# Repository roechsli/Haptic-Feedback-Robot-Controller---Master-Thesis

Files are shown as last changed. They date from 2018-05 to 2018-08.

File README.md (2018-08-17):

# Haptic Feedback Robot Controller - Master-Thesis
This is the Master Thesis written by Roman Oechslin at University of Tokyo in 2018.

Haptic Feedback Controller - Palm Pressurization by Series Elastic Actuators in a Handheld Device

In 2016 and 2017 a research group at the University of Tokyo has designed a robot controller capable of giving palm pressurization feedback using voice coil motors (VCMs).
This project is the continuation of the research and aimed at replacing the VCMs by a Series Elastic Actuator (SEA) implementation.
A new controller has been designed and tested, varying setup parameters such as the equivalent spring constant, the actuator and gear ratio or filter design.
An underlying mathematical model has been created and verified with the frequency response data from the controller.
For testing on a real robot, designed by Topy, a communication software and graphical user interface had to be written.

Based on performance analysis, design suggestions have been made and a second controller could be developed.

The transparency and latency (response delay) have been reported for both controllers with different setup parameters settings.

yoke_handheld

game_handheld

Yoke controller - gif

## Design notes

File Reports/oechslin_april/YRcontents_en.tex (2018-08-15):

% Your name
\renewcommand{\YRname}{R. Oechslin}

% Your grade/post
\newcommand{\YRgrade}{M2}

% Submission date
\newcommand{\YRdate}{2018.Apr.27}

% Your research theme
\newcommand{\YRtheme}{Haptic Feedback Controller with Palm Pressurization}

% Work plan
\newcommand{\YRplan}{
	\hspace{-4truemm}
	\begin{tabularx}{170truemm}{|p{50truemm}||X|X|X|X|X|X|X|X|X|X|X|X|}
		\hline
		\multicolumn{13}{|c|}{\parbox[c][10truemm][c]{0truemm}{} \large Research theme: \bf \YRtheme} \\
		\hline
		\hline
		\multicolumn{13}{|c|}{\parbox[c][8truemm][c]{0truemm}{} \large \bf --- Research Plan ---} \\
		\hline
		Term \textbackslash Month & 2 & 3 & 4 & 5 & 6 & 7 & 8 & 9 & 10 & 11 & 12 & 1 \\
		\hline
		% For ``Work plan'', do not change above.
		\hline
		Literature review & & & & & & & & & & & & \\
		\shadecells{2-2}
		\hline
		Design PlayStation Controller  & & & & & & & & & & & & \\
		\shadecells{2-3}
		\hline
		Test PlayStation Controller & & & & & & & & & & & & \\
		\shadecells{4-5}
		\hline
		Design Pilot Controller & & & & & & & & & & & & \\
		\shadecells{2-4}
		\hline
		Test Pilot Controller & & & & & & & & & & & & \\
		\shadecells{4-6}
		\hline
		& & & & & & & & & & & & \\
		%\shadecells{2-10}
		\hline
		Program mbed device& & & & & & & & & & & & \\
		\shadecells{5-5}
		\hline
		Redo experiments & & & & & & & & & & & & \\
		\shadecells{5-6}
		\hline
		Make third controller? & & & & & & & & & & & & \\
		\shadecells{5-7}
		\hline
		Analyze data and compare& & & & & & & & & & & & \\
		\shadecells{7-8}
		\hline
		Write Thesis & & & & & & & & & & & & \\
		\shadecells{8-8}
		\hline
	\end{tabularx}
}

% Main contents of your work
\newcommand{\YRachievement}{
	\section{Introduction}
	A lot of research on haptic feedback in handheld devices has been conducted, not only with force feedback (\cite{Prattichizzo2012}, \cite{Schoonmaker2006}), but also with pressure stimulation (\cite{Asada2016}, \cite{Nakamura2016}). The major applications for such haptic feedback devices can be found in (minimally invasive) surgical teleoperated medical systems (\cite{Bedem2009}, \cite{Enayati2016}, \cite{Tavakoli2004}, \cite{Nisky2011}), mobile augmented reality (\cite{Bermejo2017}, \cite{Hasegawa2006}) and teleoperated robotic systems (for example in space) \cite{Christiansson2007}. However this research project focuses on implementing a feedback on a handheld controller for a non-specified group of grounded wheeled robots. The controller uses pressurization feedback as a substitution for force feedback to give an intuitive%TODO say what intuitive means, give maybe a dictionary definition
	 feeling about the intrinsic state of the robot. The tests of the controller shall be made on the commercially available crawler robot from topy \footnote{\url{http://www.topy.co.jp}} using two tracks as means of transportation.
	
	As an initial approach and to be consistent with the previous research in this area \cite{AsadaPre} the robots orientation (pitch and roll angles) have been taken as state of interest. As an alternative measure, the current in the two crawler motors can be fed back to the user, to have a rough idea of used energy and to make it detectable if the robot is being stuck or blocked somewhere.
	
	\subsection{Project Description and Status Quo in the Beginning of the Project}
	The handheld controller that has been designed at Yamamoto's lab in 2016 and 2017 uses voice coil motors (VCMs) for the feedback%TODO cite paper
	. The disadvantage of these motors is that a constant voltage has to be applied to maintain a constant force. This leads to an energy-inefficient system and produces a lot of extra heat. Furthermore, the motors were rated at $13.6$ V with $2$ N/A. In the current implementation, the output force of each palm stimulator was exactly $2$ N.\\
	 The testing environment for this controller consisted in a Unity program that let the user control a tank with crawlers in an artificial landscape. When driving over the hills and smaller bumps, the user feels the magnitude of the tilt (orientation angles roll and pitch) as a pressure on the palms. \\
	The goal of this work is to replace the VCM by a set of series elastic actuators (SEAs). Different SEA-based controller designs shall be prototyped and tested on a real robot (topy). Furthermore, various feedback laws shall be implemented and tested to find the most intuitive feedback for the state of the robot.
	
	\section{Design and Analysis}
	\subsection{Series Elastic Actuators}
	%TODO The advantage of the SEA is that the elastic spring element in the system reduces the forces control to a distance control (the compression of the springs). Additionally, the elastic element is shock absorbent and stable for different environments. This means that the controller can be stable even when used with different grip stiffness, for example. \\
	 %TODO Alternatively, if the motors are non-backdriveable, a constant force can be created with only momentary motor voltage application.
	The principle of series elastic actuators is relatively simple. The concept is explained in \cite{Pratt1995} which also mentions a more accurate and stable force control and the possibility of energy storage. A thorough study of an SEA design and its analysis has been made in \cite{Junior2016}, stating that the most important parameter in the system is the spring constant. Therefore, springs with several different spring constants have been used for the analysis of this research project.\\
	In this study, two different SEA designs have been implemented and tested. The first design is based on a linear movement (constrained by a linear guideway), where the rotary motion of the motor is driving a lever, pushing the carriage back and forth. For more details, see figure \ref{fig:actuation_system_explained}. \\
	The second design is an approximated linear motion, due to a very large lever (rotational-L) actuated by a cam principle.
		
	\subsection{Design of the PlayStation Controller}
	The first design of the haptic feedback controller has been partially inspired by the existing design and partially by the commercial controllers of PlayStation. The controller can be seen in figure \ref{fig:centric_shaft_controller_smaller}.
	
	\begin{figure}[h!]
		\centering
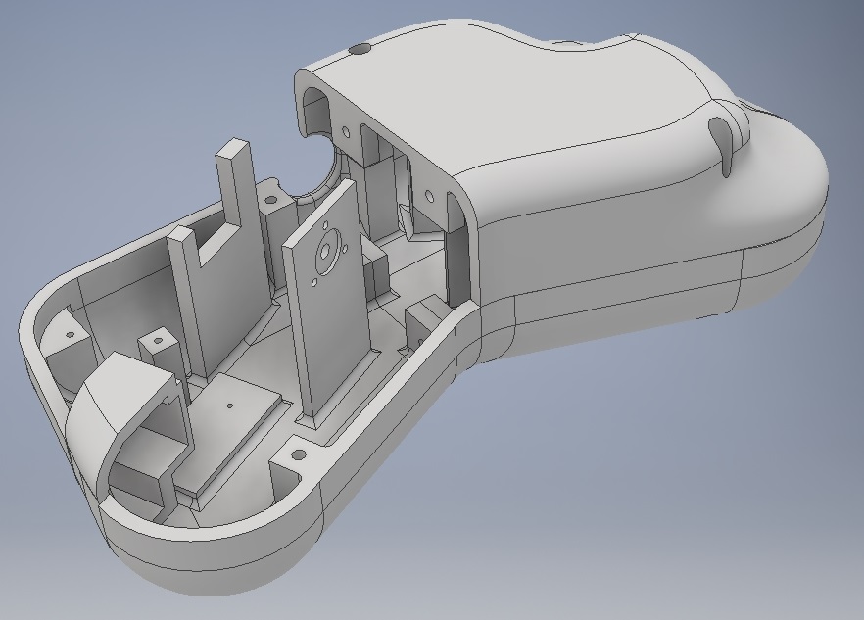
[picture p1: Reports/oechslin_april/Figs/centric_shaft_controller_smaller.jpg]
		
		\caption{3D model of the PlayStation controller.}
		\label{fig:centric_shaft_controller_smaller}
	\end{figure}
	
	This design of the controller aims at having a natural position for the hands, such that the user can hold the controller for a long time without having the hands in an awkward position. As it can be seen in the figure, the palm pads that transmit the feedback pressure to the palms are not directed perpendicularly towards the user, but rather outwards at a certain angle (refer to figure \ref{fig:centric_shaft_controller_smaller_top_view}). This can be seen as a drawback, since the user is expected to have the most intuitive feeling with a feedback opposing the driving direction (ie. perpendicular).
	\begin{figure}[h!]
		\centering
		
		\caption{3D model of the controller and the feedback direction indication.}
		\label{fig:centric_shaft_controller_smaller_top_view}
	\end{figure}

	The dimensions of the controller are 220mm in length, 110mm in width and 70mm in height. The controller is unusually thick due to the feedback actuation design. This actuation design can be seen in figure \ref{fig:actuation_system_explained}. The motor shaft is rotating a clamp link which is attached to a 3D-printed part, called connecting link. This 3D-printed part is attached to the carriage, an also 3D-printed part called L-plate, and is screwed to the linear guideway. The L-plate is connected via a set of springs (of variable spring constants) to the palm pad, thus making it an SEA. The linear guideway keeps the palm pad in a linear motion.
	\begin{figure}[h!]
		\centering
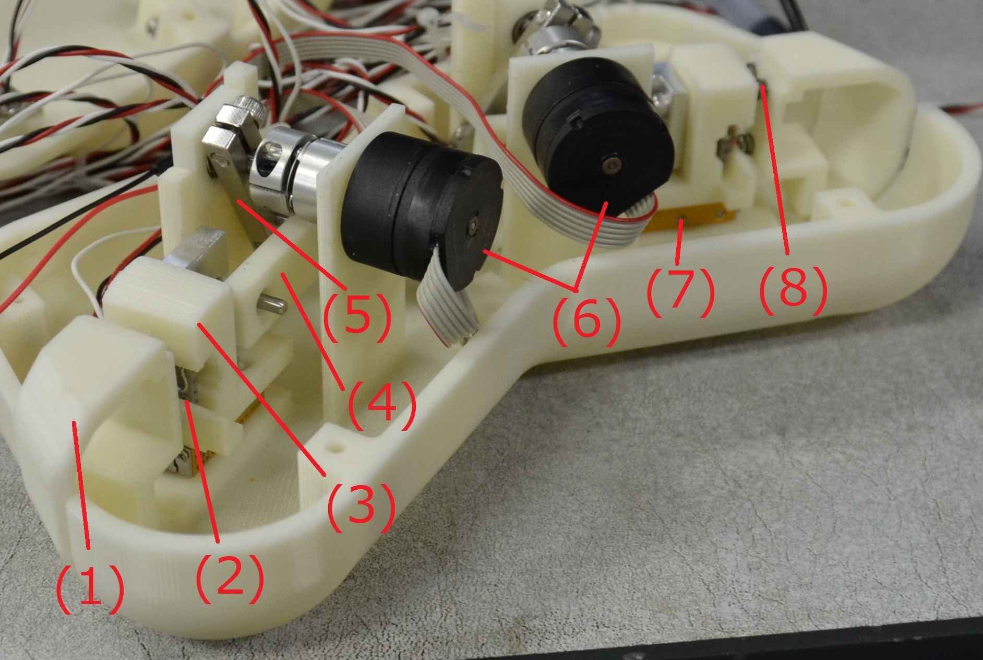
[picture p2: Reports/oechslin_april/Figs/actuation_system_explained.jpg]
		
		\caption{Actuation system with legend.}
		\label{fig:actuation_system_explained}
	\end{figure}

	The legend refering to the actuation system in figure \ref{fig:actuation_system_explained} is as follows:
	\begin{itemize}
		\item (1) : Palm pad
		\item (2) : Photoreceptor
		\item (3) : L-plate
		\item (4) : Connecting link
		\item (5) : Clamp link
		\item (6) : Motors
		\item (7) : Linear guideway
		\item (8) : Springs
	\end{itemize}

	\subsubsection{Design of the Pilot Controller}
	The 3D model of the left-hand side pilot-based controller can be seen in figure \ref{fig:left_hand_joystick_cam}. To see the inside of the controller, the cover has been removed. To assemble it three sets of screws and nuts are necessary, making it easy to assemble and take apart. Also, this design is smaller in volume than the PlayStation controller. It is therefore more slender, cheaper and faster to manufacture.
	\begin{figure}[h!]
		\centering
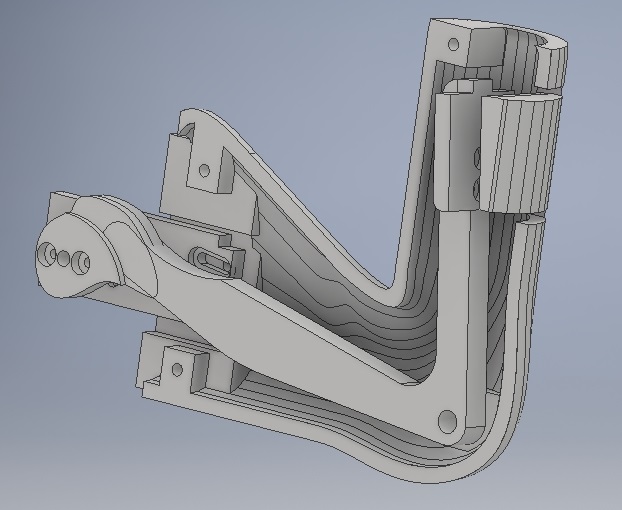
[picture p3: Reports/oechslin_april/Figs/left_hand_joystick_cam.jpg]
		
		\caption{3D model of the left-hand side controller with a removed cover.}
		\label{fig:left_hand_joystick_cam}
	\end{figure}

	In this design, the feedback motion is perpendicular towards the user and opposing the direction of motion. However, there is a slight angle at which the force is acting, due to the rotational design in the controller. But due to the large lever, this effect can be neglected. The actuation principle is based on a simple cam disk that directly pushes the rotational-L. For this design, the motors with a higher reduction gear ratio have been foreseen.

	\subsection{Test Environment and Programs}
	To test the controller, it was necessary to write a properly working environment. The topy robot is communicating via a wireless serial link. It has a prespecified communication message that consists in $70$ bytes for sending from the robot to the PC and $44$ bytes for message to receive. These messages include the bytes reserved for proper starting and ending as well as the checksum. \\
	It was thus necessary to write an application that reads out the position of the two joysticks (basic potentiometers principle) and construct a message including these joystick values as speed reference for the robot. Then the message has to be sent over the wireless serial link to the robot and the answer has to be received. The important sensor readings (inclination, current in the crawlers, passed time and battery level) have to be read out and a feedback according to the chosen feedback law has to be sent to the motors.\\
	For this purpose, the programming language processing \footnote{\url{https://processing.org/}} has been used to create a graphical user interface and to establish the serial connection. For low-level motor control purposes an Arduino Uno has been used. The parameters that can be set for testing purposes can be seen in table \ref{tab:programming_params}.
	
	\begin{figure}[h!]
		\centering
		\begin{tabular}{|l|c|l|}
			
			\hline
			Setting & Value & Units \\ \hline \hline
			Baud rate for robot serial link & $9600$ & [bps]\\ \hline
			Baud rate for Arduino serial link & $9600$ & [bps] \\ \hline
			Update rate of the processing GUI & $5$ & [Hz] \\ \hline
			Update rate of the Arduino motor controller (in theory) & $200$ & [Hz] \\ \hline
			Update rate of the Arduino motor controller (in practice) & $170$ & [Hz] \\ \hline %TODO this should be in measured not in set parameters
			Max voltage for motor & $20$ & [V] \\ \hline
			Feedback resolution & 5 out of 255 & [-] \\ \hline
			PWM frequency & $31372.55$ & [Hz]  \\ \hline
			Proportional motor gain & $1.5$  & [-] \\ \hline
			Integral motor gain & $0.0$  & [-]\\ \hline
			Derivative motor gain & $0.0$  & [-]\\ \hline
			Feedback filter  & $50$ & [\%] \\ \hline %TODO calculate cut off frequency
			Left photoreceptor MIN value & $500$ & [-] \\ \hline %TODO explain more in detail what these values mean
			Left photoreceptor MAX value & $770$ & [-] \\ \hline
			Right photoreceptor MIN value & $680$ & [-] \\ \hline
			Right photoreceptor MAX value & $770$ & [-] \\ \hline			
		\end{tabular}
		\caption{Software parameters.}
		\label{tab:programming_params}
	\end{figure}
	
	\subsection{GUI in Processing}
	The graphical user interface shows the current feedback method as well as the magnitude. It also indicates which driving direction (forward, backward or halt) is sent to the robot. Since there is no control of the battery charge in the robot, it sends battery information in its message to the PC. The processing program reads out the charge of the battery and warns the user if it is too low. It stops the program, if the battery state is critical. The feedback method can be changed by a mouse-click anywhere in the window. The GUI can be seen in figure \ref{fig:processing_gui}.
	 
	\begin{figure}[h!]
		\centering
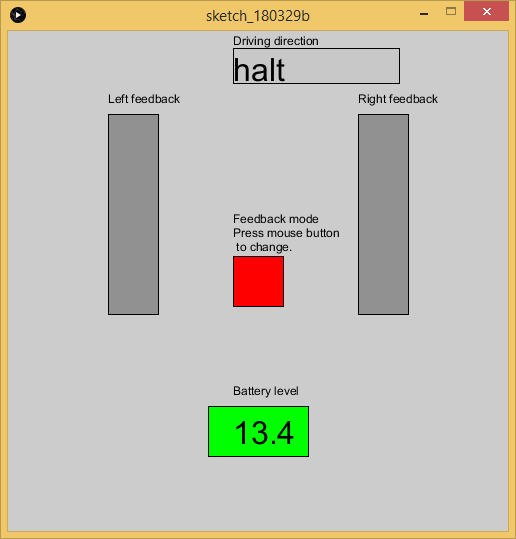
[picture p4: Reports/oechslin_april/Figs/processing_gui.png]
		
		\caption{Graphical user interface written in processing.}
		\label{fig:processing_gui}
	\end{figure}

	This application handles the messages sent to and from the robot.
	
	\subsection{Control Scheme}
	The control scheme is based on a simple proportional controller. The scheme can be seen in figure \ref{fig:control_scheme}. In the test setup the reference signal $dist_{ref}$ is given by the sinusoidal function generator. In the operational mode, this corresponds to the target output force, also called the haptic feedback force that should be felt by the user. Ideally, this shall be a function of orientation (roll and pitch) as well as the current in the two crawlers.
	\begin{figure}[h!]
		\centering
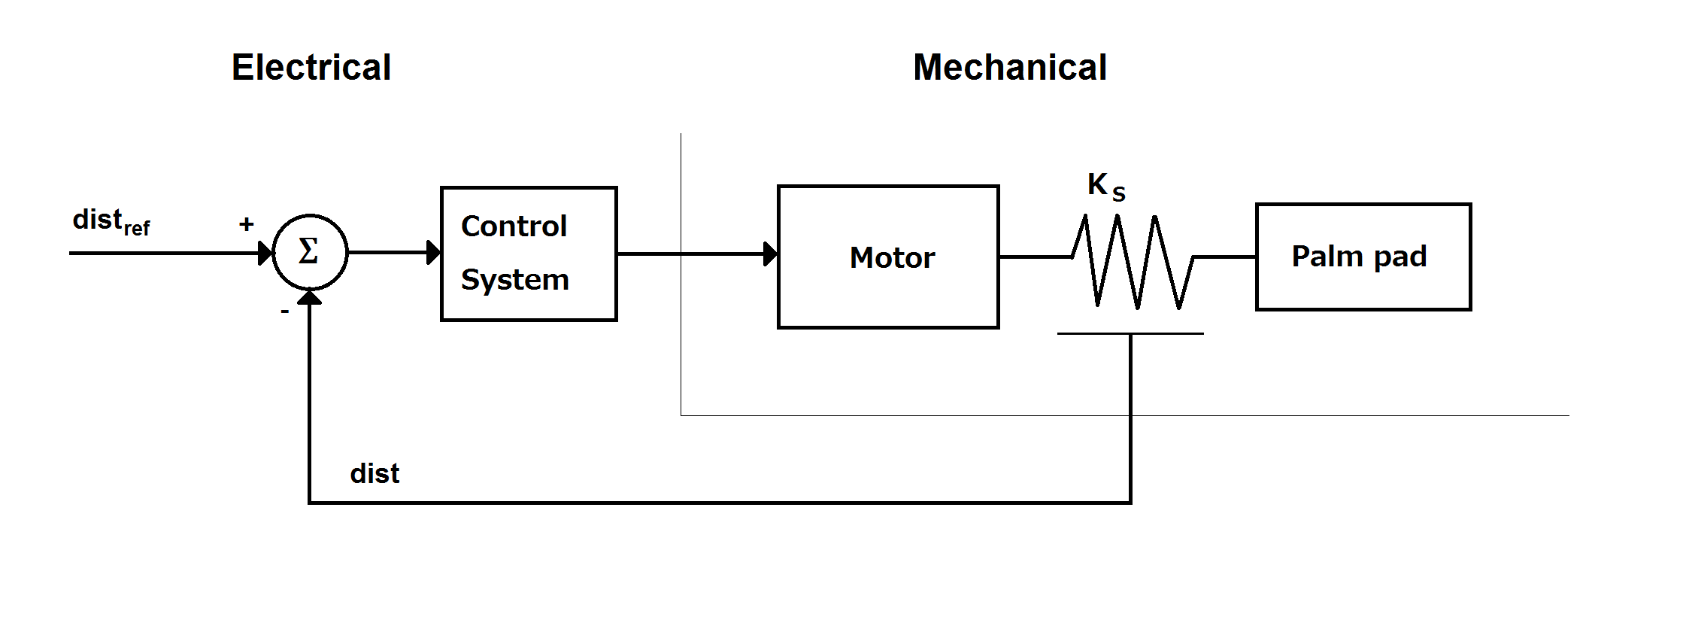
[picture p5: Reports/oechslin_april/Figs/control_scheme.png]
		
		\caption{Control scheme for the haptic feedback system.}
		\label{fig:control_scheme}
	\end{figure}
	
	\subsection{Electrical low-pass Filter}
	Before the PWM signal from the Arduino is sent to the amplifier, where it is amplified to control the motors, it has been filtered with a simple RC low-pass filter. The resistor has a value of $3.9$ k$\Omega$ and the capacitor of $0.1$ $\mu$F. This smooths out the PWM signal and has been implemented in order to avoid that the amplifier tries to follow the Arduino signal with unnecessary precision, eventually causing too much heat.

	\subsection{Photoreceptor Circuit}
	The photoreceptor that has been used is the TPR-105 from GENIXTEK CORP. Its sensing characteristics can be seen in figure \ref{fig:photoreceptor_curve}. The electrical circuit can be seen in figure \ref{fig:tpr105_circuit}. The component values are $R_1 = 330 \Omega$, $R_2 = 62$k$\Omega$ and $V_{CC} = 5$V. This receptor returns a $10$-bit value.
	
	\begin{figure}[h!]
		\centering
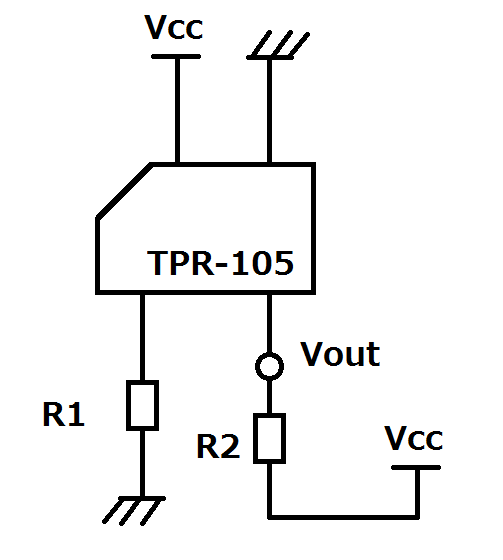
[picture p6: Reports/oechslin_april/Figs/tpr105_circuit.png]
		
		\caption{Implementation circuit of the photoreceptor.}
		\label{fig:tpr105_circuit}
	\end{figure}
	\begin{figure}[h!]
		\centering
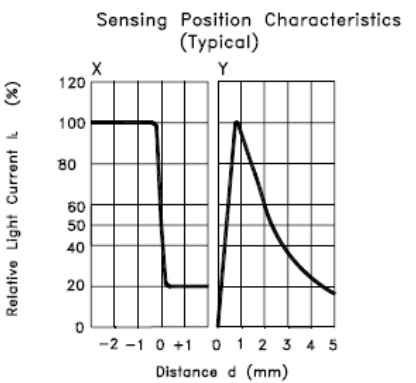
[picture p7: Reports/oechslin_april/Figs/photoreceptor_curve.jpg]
		
		\caption{Sensing characterstics of the photoreceptor TPR-105. Taken from its datasheet.}
		\label{fig:photoreceptor_curve}
	\end{figure}

	The sensing characteristics shows a nonlinear function in the range between $1$mm and $5$mm. However, as a first step, this has been interpolated linearly. To put it more precisely, the target output force has been mapped linearly to the measured distance. The operational distance lies between $4.5$mm to $5.5$mm.
	
	\section{Testing of the PlayStation Controller}
	For the two sides of the controller two different spring constants have been used. On the left-hand side, there is a set of three springs with a constant of $0.98$N/mm each. The motor has a reduction gear ratio of $33:1$. On the right-hand side the springs have a constant of $9.8 $N/mm and the motor has a reduction of $112:1$. The parameters are resumed in table \ref{tab:playstation_charac}.
	
	\begin{figure}[h!]
		\centering
		\begin{tabular}{|l|c|c|l|}
			\hline
			& Left side & Right side & Units\\ \hline \hline
			Clamp link length & 20 &  20 & [mm]  \\ \hline
			Motor reduction & $33:1$ & $112:1$ &  [-] \\ \hline
			Output torque (continous) & $30$ & $93$ & [mNm]  \\ \hline
			Output torque (intermittent) & $100$ & $180$ & [mNm] \\ \hline
			Number of springs used & $3$ & $3$ & [-] \\ \hline
			Spring constant & $0.9$ & $9.8$ & [N/mm] \\ \hline
			Equivalent spring constant & $2.7$ & $29.4$ & [N/mm] \\ \hline
		\end{tabular}
		\caption{Motor setup characteristics}
		\label{tab:playstation_charac}
	\end{figure}

	In order to conduct the frequency response analysis, the SG-4115 Function Generator has been used. The output signal was a sine wave with a peak-to-peak value of $2$V and an offset of $1.4$V. These settings have been made in order to stay within the detectable range of the Arduino $[0..5]$V. The frequency has been varied between $0.1$Hz and $35$Hz with $20$ logarithimcally spaced steps.
	
	Since the palm pads are blocked by the users hand in operational mode, they may not be considered blocked by an infinitely stiff wall. Therefore two different test setups have been created, where the palm pad has first been blocked by a screw driver in both directions, to have close to infinite stiffness, and a second setup, where the palm pads have been blocked by the users hands.
	
	\subsection{Results for Fixed Palm Pad Experiment (Pseudo Infinite Stiffness)}
	The input signal has been received as a feedback value (ie. $dist_{ref}$) and the P-controller stated in table \ref{tab:programming_params} controlled the output force by linearly mapping it to the photoreceptor distance. The measured distance has been logged and plotted. As it was expected, it is between the two extreme values stated in table \ref{tab:programming_params} (MIN and MAX). The response for the two extreme frequencies can be seen in figure \ref{fig:resp_left_hand_rigid_experim1}.
	\begin{figure}[h!]
		\centering
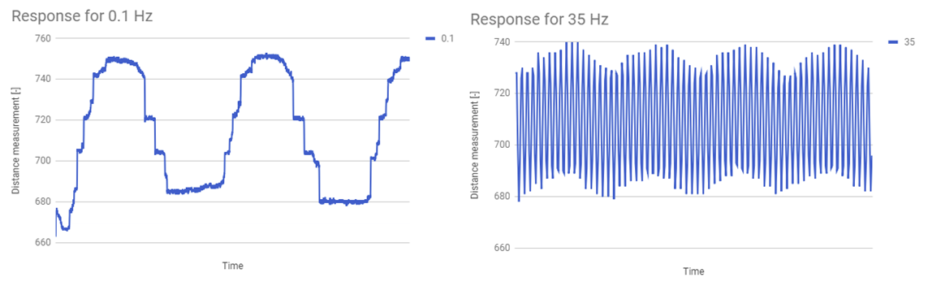
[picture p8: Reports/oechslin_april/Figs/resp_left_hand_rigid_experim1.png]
		
		\caption{}
		\label{fig:resp_left_hand_rigid_experim1}
	\end{figure}
	
	In order to find the frequency response, one is interested in the amplitude correlation between the input signal and the output signal, as given in the following equation:%TODO write how the FRF can be found, find a paper and reference it
	\begin{equation}
		H = \frac{F^*(j\omega)}{F(j\omega)}
	\end{equation}
	Where $F^*(j\omega)$ is the transfer function of the output signal and $F(j\omega)$ of the input signal.\\
	To calculate the amplitude of the output function (the measured value by the photoreceptor, corresponding to the distance between sensor and palm pad) one should ideally have a distinguishable value which is given by the maximal and minimal value of the sinusoidal output function. However, due to noise in the system, a sometimes occurring drift, interpolation aliasing and other effects such as the plateau characteristics shown in figure \ref{fig:resp_left_hand_rigid_experim1} and discussed in a later section, these minimum and maximum values are not clearly defined. Therefore, two different approaches have been chosen for the pseudo infinitely blocked palm pad experiment.
	
	First, the two quartile values ($Q_1$ and $Q_3$) have been calculated based on all the data, including outliers and noise. This is a relatively time-efficient method and is supposed to be less accurate since it sometimes includes errors such as the initial downward spike shown in the figure \ref{fig:resp_left_hand_rigid_experim1} for $0.1$Hz. The difference between these two quartile values has then been divided by the difference of the quartiles of the input signal ($Q_{3(sine)} - Q_{1(sine)}$). The results are indicated by the blue lines in figure \ref{fig:freq_resp_both_hands_rigid_experim1}.

	\begin{figure}[h!]
		\centering
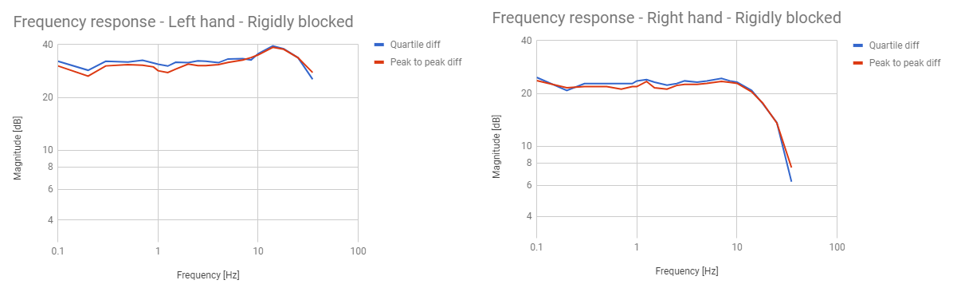
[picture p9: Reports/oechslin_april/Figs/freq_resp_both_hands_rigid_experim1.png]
		
		\caption{Frequency response analysis for both hands with a pseudo infinitely blocked palm pad.}
		\label{fig:freq_resp_both_hands_rigid_experim1}
	\end{figure}

	As an alternative output function, the amplitude has been measured manually, taking an average over several minima and maxima. This method is much more time consuming, but allows for filtering the noisy parts of the measurement, since it requires a visual representation of the measured data. These values are indicated on the same figure by the orange lines.
	
	\subsection{Results for Hand-Blocked Palm Pads Experiment}
	In the second experimental setup, the palm pads have been blocked by the hands of the user, to simulate an environment closer to the operational mode. This time, only the quartile method has been used to calculate the amplitude of the output signal. The results can be seen in figure \ref{fig:freq_resp_both_hands_soft_experim1}.
	\begin{figure}
		\centering
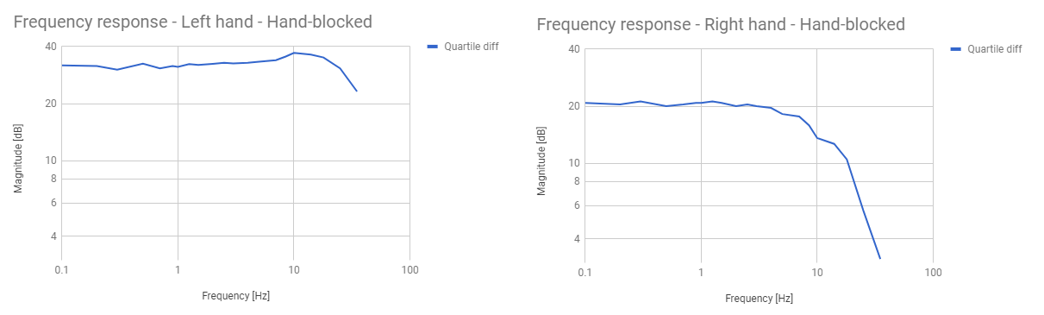
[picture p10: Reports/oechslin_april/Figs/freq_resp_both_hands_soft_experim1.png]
		
		\caption{Frequency response analysis for both hands with a hand-blocked palm pad.}
		\label{fig:freq_resp_both_hands_soft_experim1}
	\end{figure}
	
	The order of the system can be identified when looking at the slope of the Bode plot after its resonance top\footnote{Acutally, one should also consider the phase plot, but due to the reasons mentioned later in this research, this step has been skipped.}. This has been calculated for the six different curves and the following slopes have been found:
	
	\begin{tabular}{|c|c|c|}
		\hline 
		Rigid & left hand, blue line & $-54$ dB per dec \\ 
		\hline 
		& left hand, orange line & $-65$ dB per dec \\ 
		\hline 
		& right hand, blue line & $-54.8$ dB per dec \\ 
		\hline 
		& right hand, orange line & $-60.4$ dB per dec \\ 
		\hline 
		Soft & left hand & $-62.4$ dB per dec  \\ 
		\hline 
		& right hand & $-41.1$ dB per dec \\ 
		\hline 
	\end{tabular} 
	
	\section{Discussion}
	\subsection{Control Scheme and GUI}
	The control scheme is a simple proportional controller. It has been tested and decided to work well enough. If time permits, an integration and fine-tuning of an integral and derivative term can be done. \\
	There is not much to say about the GUI, however the handling of messages is not always done successfully. From time to time the processing program receives a message from the robot which is not complete. This results in accessing a cell of an array that is out of boundaries and the program crashes. To ensure the stability of the program, this case needs to be handled.
	
	\subsection{Design and Fabrication of the PlayStation Controller}
	The design of the controller is rather bulky and the actuation system might be too complex for what it is supposed to do. Due to its size, the upper and lower parts do not fit in the 3D printer and had to be cut in half and assembled by screws. This adds an extra step in manufacturing and assembly, making it more time-consuming. However the overall assembly is quite easy and tolerances have been chosen such that the whole system works. The feedback direction is not chosen optimally, if one aims at having a feedback opposing the driving direction (as seen from the robot).
	
	\subsection{Design and Fabrication of the Pilot Controller}
	This controller has almost been fully assembled, however not tested yet. It is much more simple to manufacture, as well as assemble. This design focused on having a feedback opposing the direction of motion.

	\subsection{Frequency Response Function}
	Figure \ref{fig:resp_left_hand_rigid_experim1} mainly shows two things. Firstly, there seems to be a certain step size, which is considerably more than expected. This results in only few values to attain for the photoeceptor, which can easily be seen in the response for $0.1$Hz. The second thing is, that at higher frequencies the Arduino has a too low update frequency and cannot follow the imposed sine signal, resulting in some aliasing effects. This shows that the Arduino is not capable of following frequencies higher than $35$Hz, but it also shows that the Arduino is not the right choice as a control device. The data analysis is therefore only to take with a grain of salt, since the important region after the resonance top had to be cut off. Future experiments shall be conducted using an mbed device, capable of operating at a control loop frequency of at least $1$kHz.
	
	As it can be seen in figure \ref{fig:freq_resp_both_hands_rigid_experim1} the two different methods of measuring the amplitude of the output signal share the same allures to a certain extent. This legitimizes to use the much more time-efficient approach of calculating the amplitude using the two quartile values. This argument has already been used for the data analysis in the experiment where the palm pads have been blocked by the users hand.
	
	The two figures \ref{fig:resp_left_hand_rigid_experim1} and \ref{fig:freq_resp_both_hands_rigid_experim1} show similar characteristics. Based on this, it seems appropriate to treat the two cases of pseudo infinite stiffness and hand-blocked palm pads as the same environment and for ease of analysis, only one of the two cases shall be treated.

	\section{Conclusion}
	The data that has been gathered with the Arduino as control device is only significant to a certain extent. The conclusions of using a screwdriver to block the palm pads for the experiments instead of the hand is still valid. However, the investigated frequency regions are too low to draw a meaningful conclusion and thus needs to be studied in more detail with a different control device (ie. an mbed). In addition to that, the phase diagrams have to be taken into account to confidently determine the order of the system.\\
	Furthermore, the most sensitive range of the photoreceptor is between $1$mm and $2$mm. The current implementation however is at a distance of roughly $5$mm making it much less linear and also less sensitive. This distance shall be reduced to increase linearity and sensitivity.

	\section{Outlook}
	First, the measured distance of the photoreceptor shall be changed to be in the range of $1.5$mm to $2.5$mm to have maximum linearity and sensitivity.\\
	The next step is to program the mbed to achieve the same control structure as with the Arduino, only with a higher control frequency. This should make it possible to study the system for higher frequencies. The control frequency shall be of $1$kHz, aiming for a maximum frequency of $100$Hz (Nyquist frequency is $f_s = 500$Hz and the practically achievable frequency is roughly one $5$th of this value).\\
	The experiments shall be conducted and analyzed again, this time also taking into account the phase plot in the Bode diagram. \\
	Additionally, the second controller shall be fully assembled and tested in the same manner.\\
	In parallel, the datasheet of the PMA servo motor driver shall be translated into English and the device integrated in the setup.

	%ここまで
}

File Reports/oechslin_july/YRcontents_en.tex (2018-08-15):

% Your name
\renewcommand{\YRname}{R. Oechslin}

% Your grade/post
\newcommand{\YRgrade}{M2}

% Submission date
\newcommand{\YRdate}{2018.Jul.31}

% Your research theme
\newcommand{\YRtheme}{Haptic Feedback Controller with Palm Pressurization}

% Work plan
\newcommand{\YRplan}{
	\hspace{-4truemm}
	\begin{tabularx}{170truemm}{|p{50truemm}||X|X|X|X|X|X|X|X|X|X|X|X|}
		\hline
		\multicolumn{13}{|c|}{\parbox[c][10truemm][c]{0truemm}{} \large Research theme: \bf \YRtheme} \\
		\hline
		\hline
		\multicolumn{13}{|c|}{\parbox[c][8truemm][c]{0truemm}{} \large \bf --- Research Plan ---} \\
		\hline
		Term \textbackslash Month & 2 & 3 & 4 & 5 & 6 & 7 & 8 & 9 & 10 & 11 & 12 & 1 \\
		\hline
		% For ``Work plan'', do not change above.
		\hline
		Literature review & & & & & & & & & & & & \\
		\shadecells{2-2}
		\hline
		Design PlayStation Controller  & & & & & & & & & & & & \\
		\shadecells{2-3}
		\hline
		Test PlayStation Controller & & & & & & & & & & & & \\
		\shadecells{4-6}
		\hline
		Frequency Response Analysis & & & & & & & & & & & & \\
		\shadecells{5-6}
		\hline
		Design Pilot Controller & & & & & & & & & & & & \\
		\shadecells{4-6}
		\hline
		Test Pilot Controller & & & & & & & & & & & & \\
		\shadecells{6-7}
		\hline
		& & & & & & & & & & & & \\
		%\shadecells{2-10}
		\hline
		Theoretical Analysis & & & & & & & & & & & & \\
		\shadecells{6-7}
		\hline
		Analyze data and compare & & & & & & & & & & & & \\
		\shadecells{7-8}
		\hline
		Write Thesis & & & & & & & & & & & & \\
		\shadecells{8-8}
		\hline
	\end{tabularx}
}

% Main contents of your work
\newcommand{\YRachievement}{
	
\section{Introduction}
This report is the continuation of the first two reports about the project "Haptic Feedback Controller with Palm Pressurization". The last report has stated the tracking behavior of a simple P- and PID-controlled device for a sine reference of various frequencies. Furthermore, it has suggested an experimentally identified equivalent spring damping coefficient which can be used to model the setup analytically.\\
This report is first introducing a thorough literature research into the haptic teleoperated field of study. Then it will discuss the results of the tested controller and give advice on how to choose system and setup parameters for future and related work. 

\section{Project Introduction}
\subsection{Haptics}
The Oxford Dictionaries define haptics as 

%\begin{displayquote}
"Relating to the sense of touch, in particular relating to the perception and manipulation of objects using the senses of touch and proprioception." \cite{Oxford}
%\end{displayquote}
It dates the term back to the late 19th century	and states its origin from the greek words \textit{haptikos} meaning 'able to touch or grasp' and \textit{haptein}, 'fasten'.\\
In engineering, the research in the haptic field has started to emerge in late nineteen-eighties \cite{Srinivasan1995}. Before that, man-machine interaction was mainly limited to keyboard and mouse input, which is rather unidirectional and passive and it soon has become clear that this requires a more skilled user for all kinds of operations. This directly leads to limitations in performance. Haptics can extend this unilateral interaction by providing tactile or kinesthetic information. This combination can overcome the users limitations and improve performances of high-precision tasks or high-force tasks drastically.\\
\cite{Hayward2004} states, that even though the research in the haptic domain in the past ten years has significantly increased, further investigations are necessary for the "quest for realism", especially in medical telesurgical applications where realism is key to performance. Other application domains include space operations, manufacturing, physical rehabilitation, arts or simply entertainment related devices.\\
\cite{Adams1998} states the critical elements for stability of haptic setups, mainly focusing on haptic simulations. It also motivates exploration of alternative control techniques due to the unpredictability of the human operator and the environment model.
%why haptics and what is it, needs identification

%TODO stated already in april \subsection{Previous Research at Yamamoto's Lab}
%what are the problems of the research before i came
%TODO stated already in april \subsection{Literature Review}
%what are some similar applications
%TODO stated already in april \subsection{Project Scope}
%what are my goals

\section{Stability and Transparency Trade-Off}
Even though the controller cannot be seen as a master-slave teleoperation setup, the problem settings of stability and transparency still apply. They are the main problems related to haptics and haptic teleoperation applications \cite{Christiansson2007}. Often, the stability issues arise from master-slave mass mismatch and stiffness of the environment. But high inertia also poses problems for higher frequencies. In this research however, the masses and frequencies are relatively low. \\
The stability of this controller is not only affected by the control scheme and the mechanical setup, but also by the operator, whose grasp can render a system stable or unstable \cite{Enayati2016}. Additionally, communication delays can also cause instability.\\
To gain insight into the stability, literature uses for example the root-locus method \cite{Christiansson2006} or the notion of passivity. For haptics, it can generally be assumed that the operator is passive \cite{Hogan1989}. Alternatively, one can also use the real data of the implementation to subjectively assess the stability. Here, the latter approach has been chosen.

%Hannaford shows that a cable driven hand-controller has similar frequency characteristics, where the resonance frequency is slightly more elevated than the SEA device.

\section{PlayStation-Controller Testing}
\begin{figure}[h!]
	\centering
	
	\caption{Topy robot for real-world controller test setup.}
	\label{fig:topy_robot}
\end{figure}
After the theoretical analysis and model identification of the PlayStation-controller, the setup has been put to the test. At first, the controller has been connected to the computer to communicate with the Topy robot. The communication software was written in processing \cite{Fry2018} and is explained in a different section.\\ %TODO write about the software somewhere, reference here
\subsection{Latency}
The controller was successfully able to navigate the robot, if with a delay of roughly $700$ms. The commercial controller, that was developed for the Topy robot, also had a certain delay of almost $500$ms. This delay is the difference between the instant when the joystick is pushed forward, and the moment when the robot starts moving. The feedback methods that have been tested varied between a pure pitch feedback, a combined pitch and roll feedback and a current consumption feedback law. \\%TODO state the feedback laws and reference here
The effect and magnitude of the command latency, but also of the feedback latency can be seen in figure \ref{fig:real_P_scope_13_latency_plot} and \ref{fig:real_PID_scope_14_latency_plot}.

\begin{figure}[h!]
	\centering
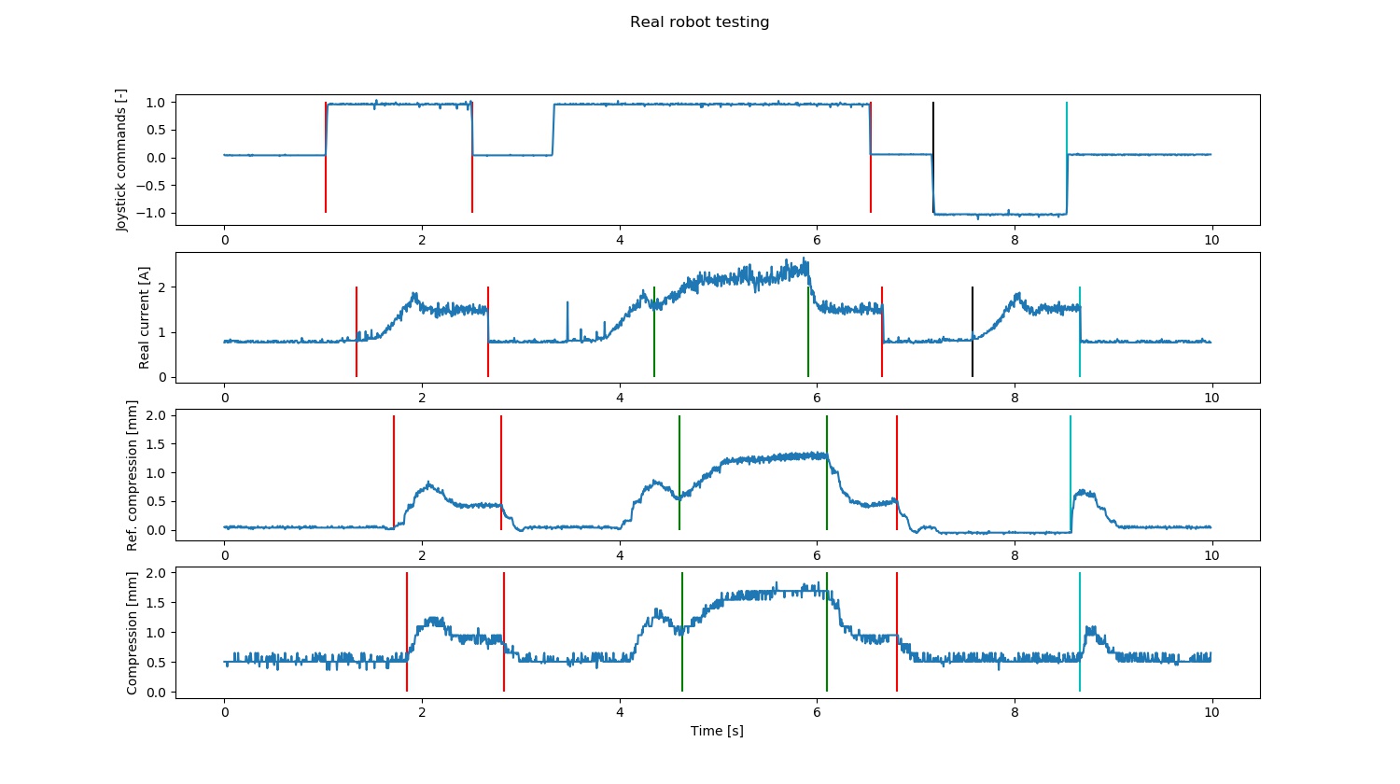
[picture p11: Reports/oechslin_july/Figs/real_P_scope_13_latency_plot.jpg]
	
	\caption{Command and behavior of Topy robot with P-controlled PlayStation controller.}
	\label{fig:real_P_scope_13_latency_plot}
\end{figure}

\begin{figure}[h!]
	\centering
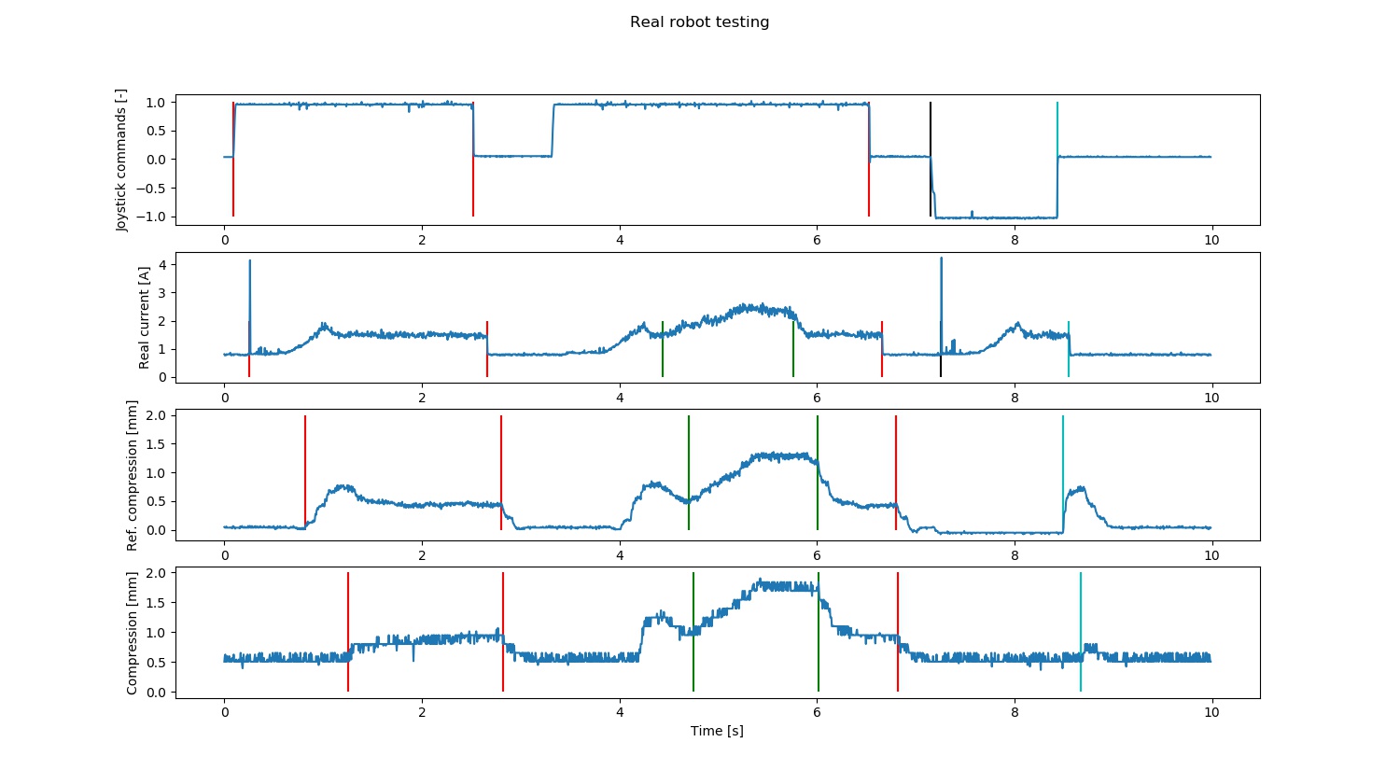
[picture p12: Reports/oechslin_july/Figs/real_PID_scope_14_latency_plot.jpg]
	
	\caption{Command and behavior of Topy robot with PID-controlled PlayStation controller.}
	\label{fig:real_PID_scope_14_latency_plot}
\end{figure}

In these figures, several interesting things have to be mentioned. First of all, the delay between sending the commands and receiving the consumed current value, which is then used as feedback value, is roughly $700$ ms. The delay between the received feedback value and the response of the distance sensor is much smaller and depends on the situation of the robot. When the robot starts to move, it takes some time until the current has built up, and the latency between the reference compression and actual compression is roughly $130$ ms for the P-controlled, and $430$ ms for the PID-controlled setup (see first red vertical lines). However, when the robot is stopped, the latency is $20$ - $30$ ms (second and third red lines).\\
In the first green lines, an external force has been applied to the robot, simulating an obstacle, which increased the consumed current and therefore also increased the desired feedback value. Again, the latency was of roughly $30$ ms. The second green lines is where the external force has been removed and the current dropped abruptly back to its normal value. The latency here was below $10$ ms.\\
Also indicated in figures \ref{fig:real_P_scope_13_latency_plot} and \ref{fig:real_PID_scope_14_latency_plot}, one can see that the feedback has been turned off when driving backwards (balck lines). However, in this scenario the feedback has been activated when standing still, ie. sending $0$ as driving speed. Since the robot is only sending the magnitude but not the direction of the current in the crawlers, the remaining current from the backward motion is fed back. This mode can easily be turned off, such that no feedback is felt when the robot is off. For reasons of completeness however, this has not been turned off and it is interesting to note, that the time between switching the command values and the reception of the feedback value has been reduced to roughly $50$ ms. \\
From these experiments one can conclude that the robot takes a long time to start driving, mainly due to internal implementation of the crawler control scheme. The total delay for this inital start-up is $820$ ms for the P-controlled and $1160$ ms for the PID-controlled version. The communication delay (joystick command and robot's reaction) is $40$ ms on average. The time between sending the joysticks commands and feeling the feedback is $240$ ms (P) and $280$ ms (PID). The full data has been gathered with an oscilloscope and can be seen in table \ref{tab:latency_table}.

\begin{figure}[h!]
	\centering
	\begin{tabular}{|l|c|c|c|c|c|c|c|c|}% Go | Stop | start pushing | let go | stop | back | stop| 
		\hline
	 	 & Start & Stop & Ext. force & No force & Stop & Back & Stop & Control\\ \hline \hline
		Joy-stick commands sent & 1.03 & 2.51 & - & - & 6.54 & 7.18 & 8.53 & P\\ 
		\hline
		Measured current in robot & 1.34 & 2.67 & 4.35 & 5.91 & 6.66 & 7.57 & 8.66 & P\\ 
		\hline
		Desired compression & 1.72 & 2.80 & 4.61 & 6.10 & 6.81 & - & 8.57 & P\\ 
		\hline
		Measured compression & 1.85 & 2.83 & 4.64 & 6.10 & 6.81 & - & 8.66 & P\\ 
		\hline \hline
		Joy-stick commands sent & 0.09 & 2.52 & - & - & 6.53 & 7.15 & 8.43 & PID\\ 
		\hline
		Measured current in robot & 0.26 & 2.66 & 4.44 & 5.76 & 6.66 & 7.26 & 8.55 & PID\\ 
		\hline
		Desired compression & 0.82 & 2.80 & 4.70 & 6.01 & 6.80 & - & 8.49 & PID\\ 
		\hline
		Measured compression & 1.25 & 2.83 & 4.75 & 6.02 & 6.82 & - & 8.67 & PID\\ 
		\hline
	\end{tabular}
	\caption{Latency table for sending joystick commands, current measured on the real robot, desired compression and measured compression. All values indicated in [s].}
	\label{tab:latency_table}
\end{figure}

\subsection{Real-Feel and Intuitiveness}
Despite the command delay, the feedback from the robot can be felt almost instantly in the user's palms. It is, as soon as the robot is moving forward, one can feel the current building up in the current consumption feedback mode for example. \\
The difference between the PID and P-controlled controllers is small, but can still be felt. In the PID-control scheme, one can feel an asymmetry between the left and right palms. This is due to the distance sensors that have different threshold values and the fact that the PID gains have been tuned for one side only. To avoid this asymmetry, it is recommended to identify different gains for the two sides or use sensors with more similar threshold values.\\
The proportional control scheme is already capable of giving an intuitive feedback of the robot's state. Especially since the feedback value is continuous and does not change much over time for all feedback modes. For these reasons, it seems appropriate to leave the controller P-controlled only.\\
\subsection{Stability}
Both control schemes are stable for various grips and feedback values, but in some cases one can feel and hear a slight instability in the PID-controlled setup. This suggests that the gains are not optimal and that they can further be tuned in future research. However, it is not possible to render the setup instable even when the user is deliberately trying to do so, acting as a non-passive element. 

\subsection{General Performance}
The overall performance evaluation of this controller is rather subjective. The output force of the SEA setup is much bigger than for the voice-coil implementation, as it has been foreseen in the design phase. Since the output force is distributed over the whole area of contact of the stimulators, the user technically feels a pressure instead of the force itself. However, one can call the feedback a pseudo-force as it has been shown in the previous research of this project \cite{Asada2016}. One important psychological aspect is the area of the stimulators. If they are too big, the pressure is much wweaker and the pseudo-force is too weak. If the area is too small, the feedback becomes punctual and the edges distort the feeling of the feedback, making it uncomfortable to use and anti-intuitive. In this controller design the stimulators have the right ratio between output force and area of contact.\\
Another psychological aspect is the direction of the feedback. This controller has an angle of roughly $ 115^\circ$ with respect to the operator's orientation. During operation the forces tend to push the palms outwards which is not entirely intuitive if one is expecting a force opposing the movement of the robot ($180 ^\circ$). This however depends strongly on the target application and the controller design can be well-suited for other environments.\\ %TODO state this somewhere (drones, bagger, car, etc.)

The biggest issue in this test setup though, is the delay of the command messages. In order to get an idea of the delay of the mechanical setup (the SEA implementation) the controller has also been tested in a purely simulated environment. This eliminates all potential delays in communication between robot and controller and the results and evaluation can be seen in the next section.

\subsection{Unity Simulation}
\begin{figure}[h!]
	\centering
	
	\caption{Unity simulation test setup.}
	\label{fig:unity_test_setup}
\end{figure}
For testing the controller in the simulated world, the Unity program from the previous research of this project has been used. With minor modifications of the control software, the controller could be tested with different feedback for the two stimulators. This time, only the combined roll-pitch feedback law has been used.\\
Since all communication delays have been eliminated, the simulated tank reacted instantly to the user's command and its orientation angles is fed back. \\
There is no latency feelable, neither when sending the commands, nor when receiving the feedback. The real-feel of the controller is better than before and even the maximum output force could be achieved when driving over the steep slopes of the environment. The range of the output force is appropriate for the desired feedback. And obstacles or slopes can be felt individually and intuitively on both sides.\\
This simulation only test shows that the latency reported in the previous section does not stem from the implementation of the series elastic actuators and justifies the choice of this actuation system.\\

\subsection{Overall Evaluation of the PlayStation Controller}
Overall one can say that the controller has achieved the performance requirements stated in the beginning of the project. \\ %TODO maybe reference here
The advantages of using SEA's are mostly the increased maximum output force and the decreased weight (VCM's tend to be very heavy due to the magnets). A drawback however is the size of the controller. The controller has been designed with several margins for dimensions and distances, leading to this bulky setup. If necessary, the design can be optimized in a future work, which would result in a much smaller controller than the current design.\\
Both control schemes (SEA and VCM) are straightforward and the output force can be controlled easily.\\
The disadvantages of the SEA implementation are the control speed and reaction time of the mechanical setup. As it has been shown in both testing environments, the mechanical response time is not the bottleneck in this setup.\\
Even though the maximum output force is enough to give a good feedback, it can be further increased. The motors that are used currently are not capable of compressing the springs to their maximal deflection. Therefore it is enough, to switch out the motors to have a higher torque. But when doing so, it should be verified, that the control speed of the motors do not affect the overall response time.\\
From the psychological points of view, the only shortcoming is the direction of the feedback which is application-specific. For this reason, and in order to write and test a parameter choice framework for future research projects, based on the current findings, a second controller has been designed.\\

\section{Design Framework}
This section provides a guideline for important design parameter choices, if one wants to design a similar haptic feedback controller based on series elastic actuators. It is mainly based on the findings from the PlayStation controller but also includes the main results of the second controller, called pilot controller. \\
Since the design framework depends on the target application, it is assumed to use the controller for robots similar to the Topy robot.

\subsection{Software and Control Choices}
In order to introduce no latency for control commands, it is important to have a high communication speed with no delay. In the current Arduino setup, one can decrease the command delay by using interrupts for the joystick commands. For immediate feedback, one can implement a feedforward control scheme that is fed from the joystick's positions directly to the stimulators.\\
The bottleneck of this setup was the fixed communication frequency of the Topy robot of maximum $5$ Hz. Due to the small changes of the feedback value, this operation frequency is still acceptable. But if one expects a highly fluctuating feedback, a higher communication frequency has to be opted for.\\
The suggested control scheme is a normal proportional controller, mainly due to the fact that it is bothersome to fine-tune the PID gains.\\
For haptic applications, it is suggested to have at least a motor control rate of $1$kHz which is the limit for the Arduino. If one opts for higher control frequencies, it is recommended to switch to an Mbed device or similar devices.
%software and control

\subsection{Mechanical Parameters}
One of the first mechanical design choices is the design of the controller itself. The PlayStation like controller has been chosen for consistency with the previous research, but also for the fact that most conventional controllers are based on this design. It is not required to copy this design, which is why a different approach has been chosen for the second controller design.\\
The feedback direction is target-application specific and results from the design. For the desired application, it is recommended to have a direct movement opposing force, as it is the case for the pilot controller design.\\
The weight only plays a minor role and any weight seems to be fine as long as the operator is comfortable with handling the controller.\\

The target point of contact with the user's palm is between the Mars and Venus region %TODO reference hand terminology
. This area is sensitive enough and can have a typical indentation of $5$mm which needs to be taken into account when calculating the necessary stroke of the stimulator. The palm pads' areas should be around $5$ to $10$ cm$^2$.\\

Another important element is the spring system that can be chosen. It is recommended to have a symmetric arrangement with springs of equal spring constant. Also, it should be paid attention to symmetries when assembling the springs, to assure a linear behavior when compressing. The length of the springs does not seem to be very important, as long as the compression is constrained to the perpendicular axis only. Testing different deflections has shown that the target stroke must be achievable and that it is better to have a margin if one wants to change the motors used to increase the output force.\\
The spring coefficients can vary and tests between $2$ and $24$ N/mm have shown promising results. %TODO emphasize these tests or outcome, and reference somehow, link to results or data

The motors greatly influence the performance of the controller. The reduction ratio should be high enough to guarantee the target output force, while assuring the desired control speed. The target output torque can be used to calculate the output force approximately. But one should keep in mind that some energy is lost in friction and efficiency of the motor and gear assembly.
%mechanical (springs (length, size, arrangement), motors (speed/reduction, output torque), design (orientation, stimulators, etc.), weight)

\subsection{Electrical Parameters}
The electric components that have been used are mainly the potentiometer for the joysticks and the photoreceptors for distance sensing.\\
The photoreceptors have very different characteristics and all thresholds need to be identified individually. Furthermore, the output function is not linear for a big range of distances and the sensitivity also depends on the distance. If a high performance is expected from the controller, it is recommended to find a different solution or a better performing sensor.\\
Furthermore, it is recommended to filter the motor commands to convert the Arduino output PWM to a more steady voltage level, to protect the amplifiers from overfitting the signal.\\
Also, it was necessary to have a voltage follower (a simple operational amplifier with unitary gain) in order to reduce interfering effects on the distance sensors.
%electrical (sensors, joystick)

%say what parameters are important, how they affect the controllers, etc.
%say what i have found for my PS controller and what i can change

\section{Pilot Controller}
Based on the framework from the previous section, a new controller has been devised, mainly focusing on a different design and on a more optimal feedback direction.

\subsection{Working Principle (cam)}%TODO put text from april here
Has already been stated in April's monthly report.

\subsection{Design and Parameters}
When designing this controller, the design of an airplane yoke has been used as a model. Therefore it is from now on called pilot controller. In order to have a nice fit to the palms, the circumference has been chosen to be close to the airplane yokes or conventional car steering wheels. The joysticks' position is such that the stimulator touches the same area of the palm as in the previous controller and research (Venus and Mars area of the hand). This time the feedback direction is perpendicular towards the user, which ensures a more intuitive feeling for the desired application.\\
The most important parameters in this system are the length of the lever and the springs. For the prototype, the levers length has been fixed to roughly $100$ mm and a set of four springs with $1$ N/mm each have been used. Their length is $10$ mm and they have an allowable deflection ratio of $40$\%.\\
The stimulators area is kept almost the same with $7.5$ cm$^2$.\\
The motors play an important role again and for this design, the motors with the reduction gear of $33:1$ have been implemented.

When designing the rotational cam part, a spiral-like freeform has been drawn to keep the angle-to-distance ratio as linear as possible. The operational range of the motor shaft is $110 ^\circ$. It is, the full stroke of the lever can be achieved by rotating the motor shaft and the attached rotation cam by this angle.\\

The operational distance for the photoreceptors is between $11$ mm and $8$ mm. 
Again the operational range of the photoreceptors can be identified.

\begin{figure}[h!]
	\centering
	\begin{tabular}{|l|c|c|c|c|c|}
		\hline
		& Sensor reading & Distance & Sensor reading & Distance & Max output  \\
		& MAX (rest) & (rest) & MIN (compression) & (compression) & force \\ \hline \hline
		Left side & 800 & 11mm & 550 & 8mm & 12N \\ \hline
		%Right side & 870 &2.2mm & 700 & 8mm & 10.8N \\ \hline
	\end{tabular}
	\caption{Identified operational range for the photoreceptors in the pilot controller.}
	\label{tab:oper_range_pilot}
\end{figure}
%state the parameter choices that i have made based on previous findings
\subsection{advantages and disadvantages}%TODO is this really necessary or can i write it under design and parameters
%state advantages and disadvantages
\subsection{Analytical results}
%state analytical results (if available)
\subsection{Frequency Response Analysis}
Similar to the previous frequency response analysis, the controller has been tested when feeding a sine wave in the range of $1$ Hz up to $100$ Hz. The result for the P-controlled device can be seen in figure \ref{fig:pilot_bode_P02}

\begin{figure}[h!]
	\centering
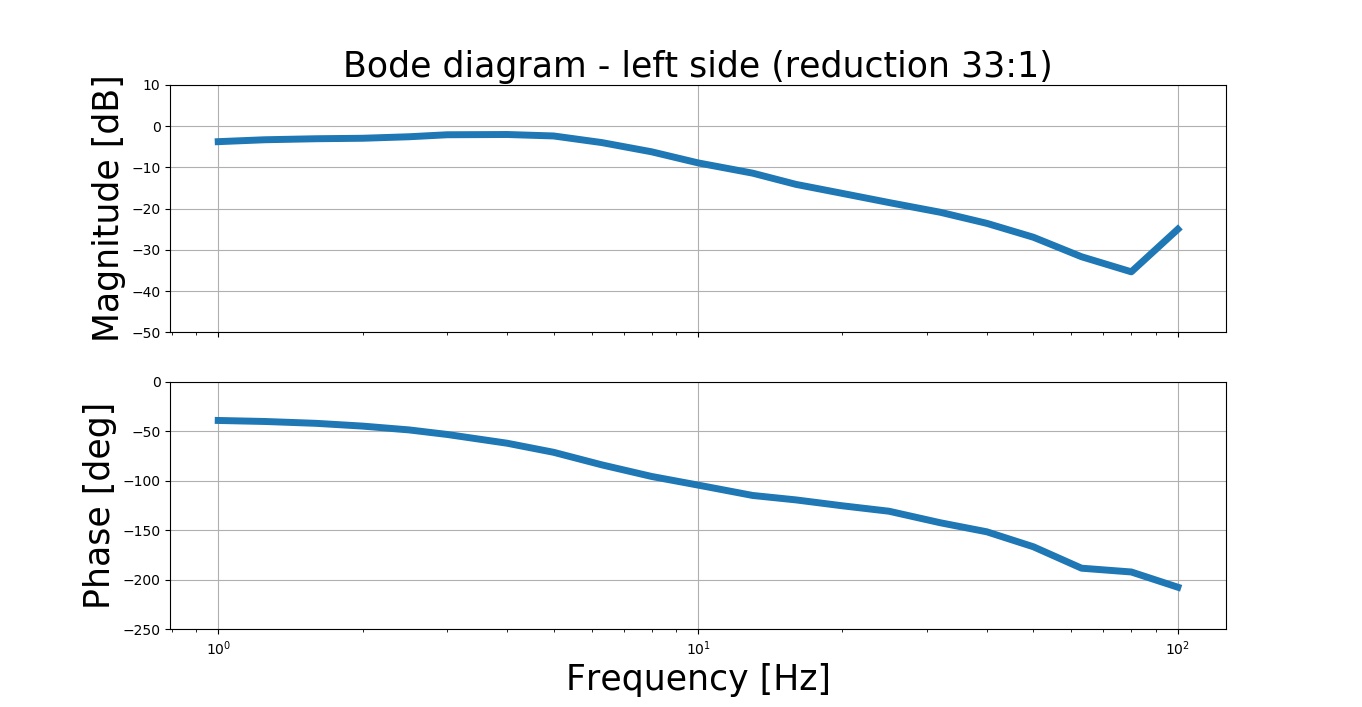
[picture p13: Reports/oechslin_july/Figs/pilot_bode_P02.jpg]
	
	\caption{Frequency response function of the P-controlled pilot controller.}
	\label{fig:pilot_bode_P02}
\end{figure}

The bode diagram resembles the one of the previous setup, with the main difference, that it seems to be shifted towards lower frequencies. The phase offset changes almost linearly from $45 ^\circ$ to $200 ^\circ$. Analogously, it is argued that the initial phase lag for low frequencies stems from the different filters that have been implemented in the same manner. Regarding the magnitude plot however, it is important to note that the resonance frequency is much lower, namely $4$ Hz.\\

In the current design of the pilot controller, the lever is roughly $100$ mm and has been fabricated using an $8$ mm thick poly-acetal plate. Due to the relative low thickness, the lever can deform and thus leads to an additional spring element in the system. Furthermore, the rotation cam is not coupled to the lever and thus cannot make pull it back in order to decrease the springs' compression, even if a negative voltage is applied. This leads to a lower overall performance and results in a lower resonance frequency.\\
In order to deal with this issue, it is recommended to preload the lever that pulls it back faster than normal, or couple the rotational cam with the lever.

\subsection{Pilot-Controller Testing}
%state real feel, latency, transparency and stability
\subsection{Outlook}
%state possible improvements for future work

\section{Discussion}	

\section{Conclusion}

\section{Outlook}

	%ここまで
}

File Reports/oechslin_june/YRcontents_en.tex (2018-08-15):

% Your name
\renewcommand{\YRname}{R. Oechslin}

% Your grade/post
\newcommand{\YRgrade}{M2}

% Submission date
\newcommand{\YRdate}{2018.Jul.3}

% Your research theme
\newcommand{\YRtheme}{Haptic Feedback Controller with Palm Pressurization}

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

% Main contents of your work
\newcommand{\YRachievement}{
	
	\section{Introduction}
	This report is the continuation of the first two reports about the project "Haptic Feedback Controller with Palm Pressurization". The last report has left off with the idea of implementing a voltage follower and suggested to retake measurements to create a Bode diagram. Furthermore, it has been suggested to create an analytical model and analysis of the setup in order to run simulations to identify setup parameters such as the equivalent spring constant, gain values or motor parameters.

	\section{Theoretical analysis}
	% I can check with existing papers and take their block diagram
	To come up with a theoretical analysis of the transfer function, a simplified mechanical schematic has been drawn. This schematic can be seen in figure \ref{fig:mechanical_schematic}.
	\begin{figure}[h!]
		\centering
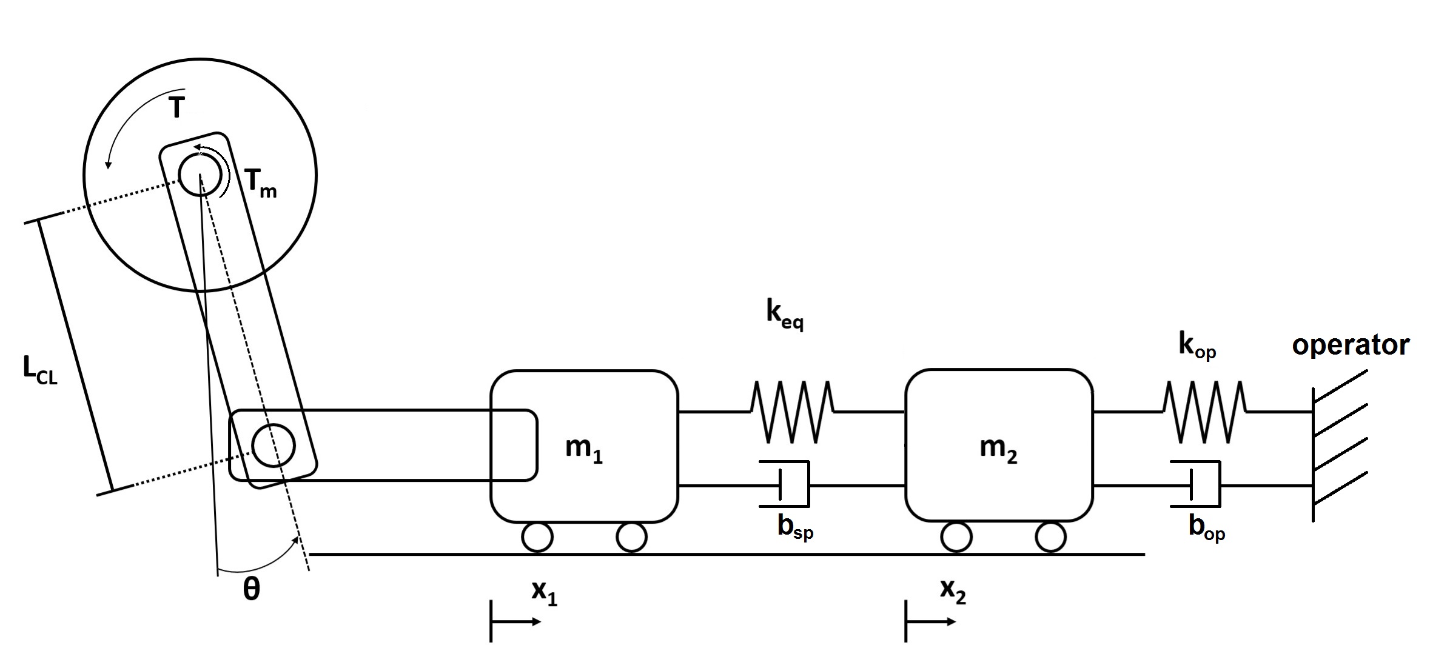
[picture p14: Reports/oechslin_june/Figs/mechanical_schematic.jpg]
		
		\caption{Simplified mechanical schematic of the actuation system with the stimulator.}
		\label{fig:mechanical_schematic}
	\end{figure}
	The equations of motion can be formulated with the major parameters defined in the schematic. A full explanation of all parameters can be seen in table \ref{tab:setup_params}. The variables with subscript $1$ refer to the first mass element, the carriage in its guideway, whereas variables with subscript $2$ refer to the stimulator, also known as the palm pad. For the motor the subscript $m$ has been used.
	
	\begin{figure}[h!]
		\centering
		\begin{tabular}{|l|c|c|}%designator | explanation | unit
			\hline
			 Designator & Explanation & Unit \\ \hline \hline
			$T_m$ & Motor torque & [Nm]\\ 
			$T$ & Output torque acting on carriage& [Nm]\\
			$\theta_m$ & Motor angle & [rad]\\
			$\theta$ & Clamp link angle & [rad]\\  
			$L_{CL}$ & Clamp link length & [m]\\
			$m_{1}$ & Mass of the carriage in its guideway & [kg]\\
			$m_{2}$ & Mass of the stimulator & [kg]\\
			$x_{1}$ & Position of the carriage in its guideway & [m]\\
			$x_{2}$ & Position of the stimulator & [m]\\
			$k_{eq}$ & Equivalent spring constant & [N/m]\\
			$b_{sp}$ & Spring damping coefficient & [Ns/m]\\
			$n$ & Reduction gear ratio & [-]\\
			$k_{op}$ & Spring constant of the operator & [N/m]\\
			$b_{op}$ & Damping coefficient of the operator & [Ns/m]\\
			$J_T$ & Total inertia of mechanical setup & [$\textit{kgm}^2$]\\
			\hline
		\end{tabular}
		\caption{Setup parameters}
		\label{tab:setup_params}
	\end{figure}
	
	\subsection{Assumptions}
	First of all, it is important to mention that the transfer function is non-linear, due to the motor angle $\theta_m$ that determines the force acting on the carriage with mass $m_1$. As an initial approach however, this effect has been neglected. More specifically, it is assumed that $\theta \ll 1$ and $\cos{(\theta)} \frac{T_m}{L_{CL} } = F_{carr} $ becomes $\frac{T_m}{L_{CL} } \simeq F_{carr} $. Here the angle $\theta$ is the angle of the lever, pushing the carriage (ie. $\theta_m = n \theta$). \\
	Furthermore, there are several types of friction in the system: the intrinsic friction within the motor and its reduction gear, inside the bearings and the carriage in its guideway. Additionally the springs have a non-negligible damping coefficient. In this work the overall friction and the spring damping have been merged and are represented by the friction coefficient $b_{sp}$. The stimulator, is not in contact with the controller, but with the operator. To model the damping of the skin of the operator and the friction between the skin and the palm pad, the damping coefficient $b_{op}$ has been introduced. Similarly the spring constant of the operator's skin is modeled by $k_{op}$.\\
	
	\subsection{Spring Constant and Damping Coefficient of the Operator's Hands}
	The order of magnitude of the two coefficients $k_{op}$ and $b_{op}$ are discussed in \cite{Kuchenbecker2003} \cite{Park2014} \cite{Speich2005}. They all indicate parameters varying in the same order of magnitude, namely $k_{op} \simeq 400$N/m and $b_{op} \simeq 5$Ns/m.\\
	
	\subsection{Identification of the Spring Damping Coefficient}
	The damping coefficient of the spring $b_{sp}$ can be found by comparing the theoretical results of the frequency response analysis with the experimental findings. In fact, for the experimental setup, the stimulator has been fully blocked and therefore the operator's spring coefficient can be seen as infinitely stiff.\\
	By varying $b_{sp}$ and Bode-plotting the results of the analytical transfer function, the coefficient's order of magnitude can be found. In order to do so, the analytical transfer function has to be identified.
	
	\subsection{Expected Transfer Functions}
	The system can be cut into two major transfer functions. The block diagram including these two transfer functions is depicted in figure \ref{fig:2tf_block_diagram}. 
	
	\begin{figure}[h!]
		\centering
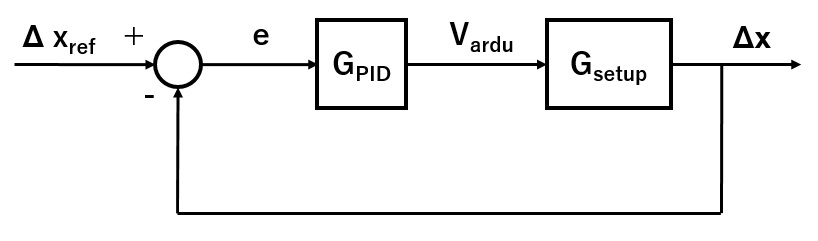
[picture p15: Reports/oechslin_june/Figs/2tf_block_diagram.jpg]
		
		\caption{Block diagram with two different transfer functions.}
		\label{fig:2tf_block_diagram}
	\end{figure}
	According to this figure one can obtain a transfer function of the following form:
	\begin{equation}
		F(s) = G_{PID}(s)G_{setup}(s) = \frac{V_{ardu}}{E}\frac{\Delta X}{V_{ardu}} = \frac{\Delta X(s)}{E(s)}
		\label{eq:complete_tf}
	\end{equation}
	where $V_{ardu}$ is the voltage output of the arduino for controlling the motors. Using this form one can calculate the individual transfer functions and finally relate the compression of the springs $\Delta x$ to the compression given as reference $\Delta x_{ref}$, since $\Delta X_{ref} / \Delta x = F/(1+F)$.
	
	\subsubsection{PID Transfer Function}
	The transfer function given by the PID-controller is very straight-forward and can be taken out of any control theory book \cite{Dutton1997}. 
	Since the arduino has limited resolution with floating point operations, the error and reference has been converted into micrometers. To keep the gains consistent between the arduino code and the matlab script for analytical analysis, the multiplication factor $K_{\mu m}$ to get from the reference distance in meters to micrometers has been introduced. Furthermore, an offset has been added ($K_{bit-offset} = 128$) to allow for negative armature voltages and lastly the PID value has been converted to the arduino output voltage, where $255$ corresponds to $5$ V. The transfer function is given in equation \ref{eq:tf_pid}. 
	\begin{equation}
		G_{PID} (s) = \frac{V_{ardu}(s)}{E(s)} = (K_{\mu m} (K_P + \frac{K_I}{s} + K_Ds) +K_{bit-offset}) K_{PID2Vardu}
		\label{eq:tf_pid}
	\end{equation}
	Finally, there is also the gain of the amplifier in voltage mode, which converts the voltage of the arduino into the voltage applied to the motors. This gain is $K_{ampl} = 10$Volt/Volt. To this voltage an offset voltage of $V_{offset} = -25$V is added.\\
	
	\subsubsection{Motor Equations}
	The second transfer function relates the motor torque $T_m$ to the arduino voltage as well as the output $\Delta x$ to $T_m$. Due to the back electromotive force these two parts are related and have to be treated as a whole.
	
	The output torque $T_m$ of the motor can be calculated using the sum of all torques and the conversion parameters intrinsic to the motor.\\
	Similar to the setup and analysis in \cite{Junior2016} the equations of the motor are given as:
	\begin{equation}
		L_a \frac{di_a}{dt} + R_a i_a + K_{emf} \dot{\theta }_m = V_a
	\end{equation}
	where $L_a$ is the armature inductance, $R_a$ the armature resistance and $i_a$ the armature current of the motor. $K_{emf}$ is the back electromotive force constant also given by the motor. $V_a$ is the armature voltage and $\theta_m$ is the angle of the motor shaft.\\
	Furthermore, with Newton's law, the sum of all torques must be zero, or:
	\begin{equation}
		J_{T} \ddot{\theta }_m - \frac{k_{eq} L_{CL}}{n} \Delta x - \frac{b_{sp} L_{CL}}{n} (\dot{x}_2 - \dot{x}_1)  = T_m = K_{\tau} i_a
		\label{eq:torques}
	\end{equation}
	In equation \ref{eq:torques} the parameter $J_{T}$ stands for the total equivalent inertia of the motor, the clamping link and the carriage of mass $m_1$.  $K_{\tau}$ is the proportional current torque gain constant. The moment of inertia can either be calculated as the sum of all inertias seen by the motor shaft, or measured in a simple test.\\ 
	
	\subsection{Analytical Inertia Identification}
	The total inertia of the system is determined by the inertia of the rotor and gears $J_m$, the inertia of the clamp link $J_{CL}$ as well as the inertia of the carriage assembly with mass $m_1$. The last one can be found by simplifying the load to a point mass at distance of the clamp link's length $L_{CL}$, which yields a moment of inertia of $J_{carr} = m_1 L_{CL}^2$.
	The gear box affects the inertia seen by the motor shaft by the square of its ratio $n$:
	\begin{equation}
		J_{reflected} = \frac{ J_{load}}{n^2}
	\end{equation}

	We therefore have a total inertia of:
	\begin{equation}
		J_T = J_m + \frac{J_{CL}}{n^2} + \frac{ m_1 L_{CL}^2}{n^2}
	\end{equation}
	where $J_{CL}$ can be calculated by approximating it as a cantilever with an off-center axis of distance $L_{CL} /2$ \footnote{(2018, June 19th) retrieved from \url{http://www.orientalmotor.com/technology/motor-sizing-calculations.html}}: %Source: http://www.orientalmotor.com/technology/motor-sizing-calculations.html
	
	\begin{equation}
		J_{CL} = \frac{1}{12}m_{CL}(A^2 + B^2 + 12l^2)
	\end{equation}
	where $A$ and $B$ are the width and length respectively.\\
	The calculated total moment of inertia for the motor with a reduction ration of $n = 112$ is $J_T = 6.87 \times 10^{-8}$ $\textit{kgm}^2$.
	
	\subsection{Experimental Inertia Identification}
	Alternatively, one can approximate the total moment of inertia by applying a constant current on the motor and measuring the acceleration. In this case the traveled distance has been derivated twice to find the acceleration, which results in an amplification of errors. Furthermore, the constant current has been kept very low, (between $20$ and $100$ mA), which led to a slow movement and therefore higher friction impact on the measurements. However, the results are consistent with the theoretically calculated values:
	$$ J_T = \frac{7.5 \times 10^{-4}}{n^2} = 5.98 \times 10^{-8} \textit{ kgm}^2$$ 
	
	\subsection{Relating $\Delta X$ to $\theta$}
	The conversion between the angle $\theta$ and the carriage's traveled distance $x_1$ can be found by assuming that the horizontal displacement of the carriage is given by $L_{CL} sin(\theta) = x_1$. For small angles of $\theta$ the Taylor expansion gives:
	\begin{equation}
		L_{CL} \theta \simeq x_1
		\label{eq:assum}
	\end{equation} 
	
	The output $\Delta x$ is the compression of the springs and is given by $\Delta x = x_2 - x_1$. For finding $x_2$ the equation of motion given by Newton's law has been considered.
	
	\begin{equation}
		m_2 \ddot{x}_2 = -k_{eq} (x_2 - x_1) - b_{sp} (\dot{x}_2 - \dot{x}_1) - k_{op} x_2 - b_{op} \dot{x}_2
		\label{eq:mov_stimul}
	\end{equation}
	In the case where the stimulator has been blocked by a wall, $\dot{x}_2$ has been forced to zero. Using the Laplace transform and equation \ref{eq:mov_stimul} one finds the expression of $x_2$:
	
	\begin{equation}
		X_2 = -\frac{k_{eq} + b_{sp} s}{s^2 m_2 + b_{op} s + k_{op}} \Delta X
		\label{eq:x2dx}
	\end{equation}
	
	\subsubsection{Motor and Spring Transfer Function}
	Combining all the equations one can find the final block diagram, which can be seen in figure \ref{fig:block_diagram}
	\begin{figure}[h!]
		\centering
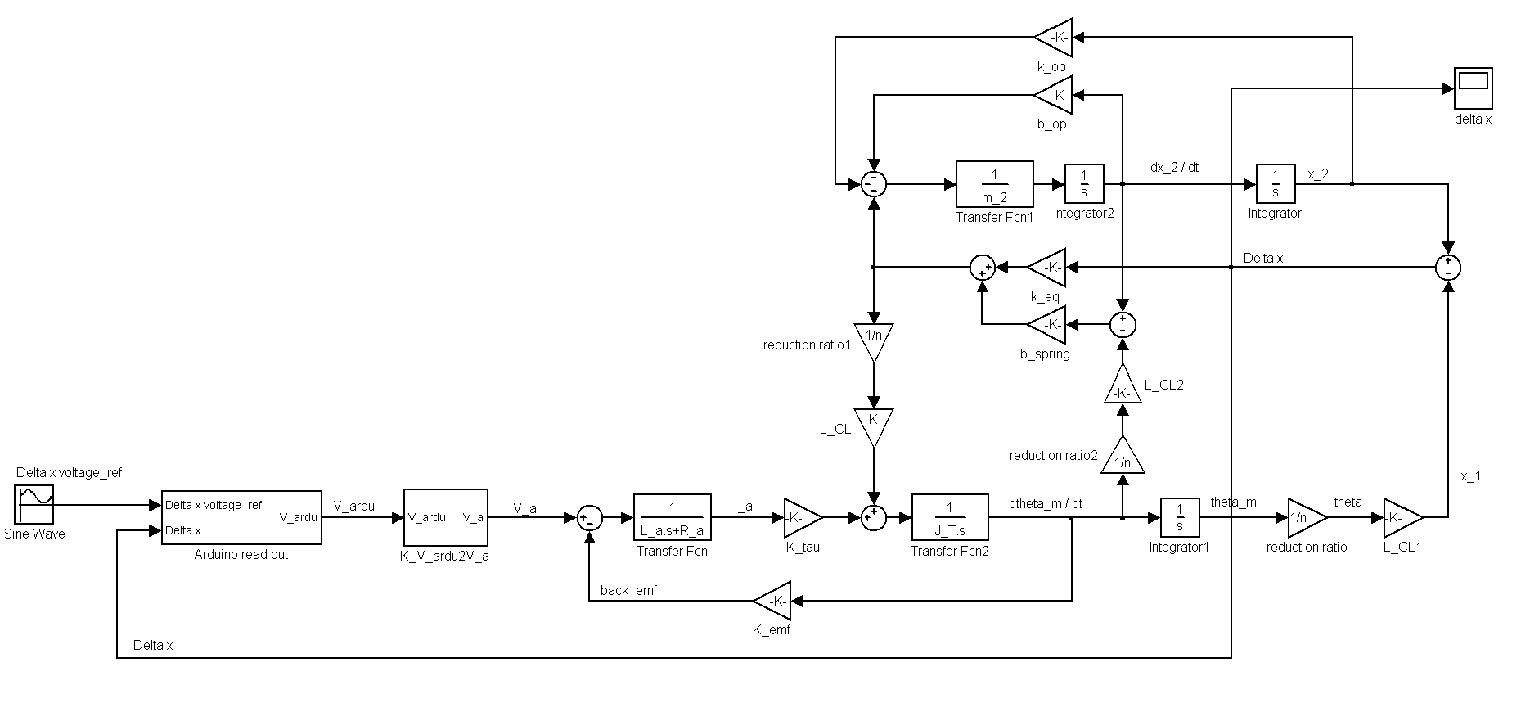
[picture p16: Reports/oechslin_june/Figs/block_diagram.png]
		
		\caption{Complete block diagram relating the output $\Delta x$ to the input $\Delta x_{ref}$.}
		\label{fig:block_diagram}
	\end{figure}

	From this diagram and the equations mentioned above, one can obtain the transfer functions that relate the output $\Delta x$ and input $\Delta x_{ref}$ as introduced in equation \ref{eq:complete_tf},
	where $\Delta X(s)$ and $\Delta X_{ref}(s)$ are the Laplace transforms of the output and input functions respectively. \\
	It is thus possible to study the frequency response by simulating this setup with the assumptions mentioned earlier.
	
	\subsection{Main Equations for Analytical Transfer Function}
	\begin{equation}
		\Delta X_{ref} - \Delta X = E
		\label{eq:error}
	\end{equation}
	
	\begin{equation}
		((K_P + K_D s + \frac{K_I}{s})E K_{\mu m} + K_{bit-offset}) K_{PID2Vardu} K_{ampl} + V_{offset}= V_a
		\label{eq:PID}
	\end{equation}
	
	\begin{equation}
		\frac{V_a - K_{emf}\dot{\theta}_m}{L_a s + R_a} K_{\tau} + F_{coupled} = J_T \ddot{\theta}_m
		\label{eq:motor_torques}
	\end{equation}
	
	\begin{equation}
		F_{coupled} = (k_{eq} + b_{sp}s) \frac{L_{CL}}{n} \Delta X
		\label{eq:fcoupled}
	\end{equation}
	
	\begin{equation}
		\theta_m = \frac{n}{L_{CL}} X_1 = -\frac{n}{L_{CL}}(1 + \frac{k_{eq} + b_{sp}s}{m_2 s^2 + b_{op}s + k_{op}}) \Delta X
	\label{eq:theta}
	\end{equation}
	
	Note that the constant offsets in equation \ref{eq:PID} are for pure symmetrical reasons and will cancel each other out, since $K_{bit-offset} K_{PID2Vardu} K_{ampl} + V_{offset} = 0$ and the equation becomes $ ((K_P + K_D s + \frac{K_I}{s})E K_{\mu m} ) K_{PID2Vardu} K_{ampl}= V_a$. This is the equivalent to a standard PID form with gains $K'_P$, $K'_D$ and $K'_I$.\\
	In the case of the experimental setup the palm pad has been blocked and therefore $x_2$ has been forced to be constant. The last equation becomes thus: $\theta_m = - \frac{n}{L_{CL}} \Delta X$.
	
	\subsection{Tracking Behavior of the P-controller}
	The tracking behavior of the P-controlled setup can be seen in the following figures.
	\begin{figure}[h!]
		\centering
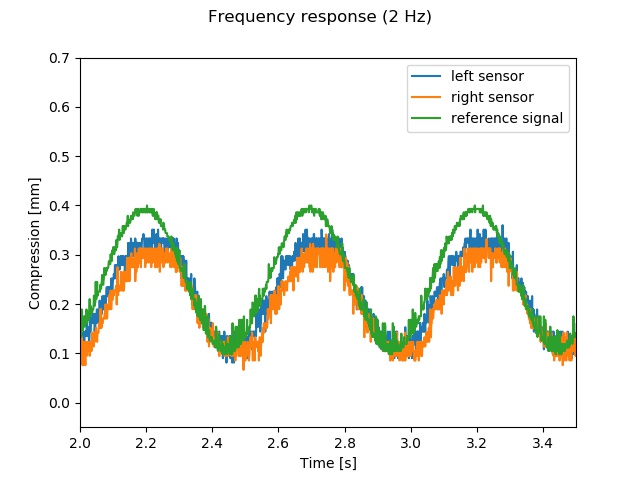
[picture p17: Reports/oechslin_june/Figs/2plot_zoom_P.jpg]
		
		\caption{Tracking behavior of the P-controller for $2$ Hz.}
		\label{fig:2plot_zoom_P}
	\end{figure}
	\begin{figure}[h!]
		\centering
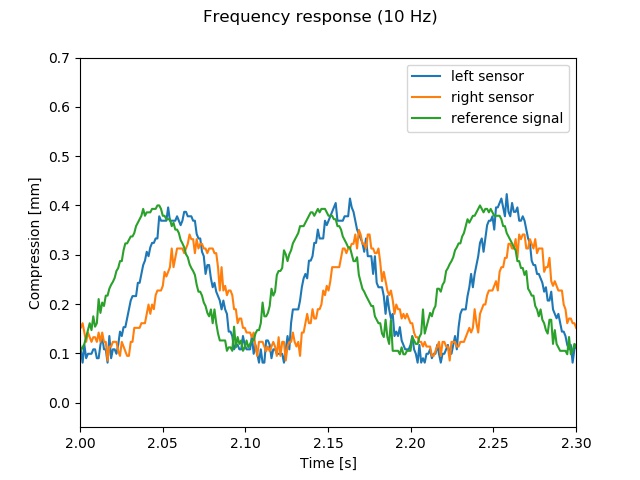
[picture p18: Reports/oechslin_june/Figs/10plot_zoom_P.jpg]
		
		\caption{Tracking behavior of the P-controller for $10$ Hz.}
		\label{fig:10plot_zoom_P}
	\end{figure}
	
	%show picture, explain problem of steady state offset, find PID values
	
	\subsection{Comparison of Results - P-controller and Experimental Data}
	The analytical transfer function has only been calculated for a specific set of spring damping coefficients $b_{sp}$. The results for the uniformly spaced values between $100$Ns/m and $400$Ns/m are depicted in figure \ref{fig:bode_all_combined_P02}. The gains that have been used are for a P-controller, it was namely $K_P' = 39.2 \frac{\textit{V}}{\textit{mm}}$. The simulation result that was closest to the experimental setup can be seen in figure \ref{fig:bode_sp_damp300_P02} and the corresponding transfer function is:
	\begin{equation}
		%\frac{\Delta X}{\Delta X_{ref}} = \frac{7.04\times 10^{-3} s^2 + 288 s + 2.94\times 10^{6}}{1.09\times 10^{-10}s^5 + 6.69\times 10^{-6}s^4 + 0.137 s^3 + 940s^2 +6.45 s + 2.95\times 10^{6}}
		\frac{\Delta X}{\Delta X_{ref}} = \frac{1.23 \times 10^3}{3.24\times 10^{-6}s^3 + 6.67\times 10^{-2}s^2 + 8.48s + 1.23 \times 10^3}
	\end{equation}

\begin{figure}[h!]
	\centering
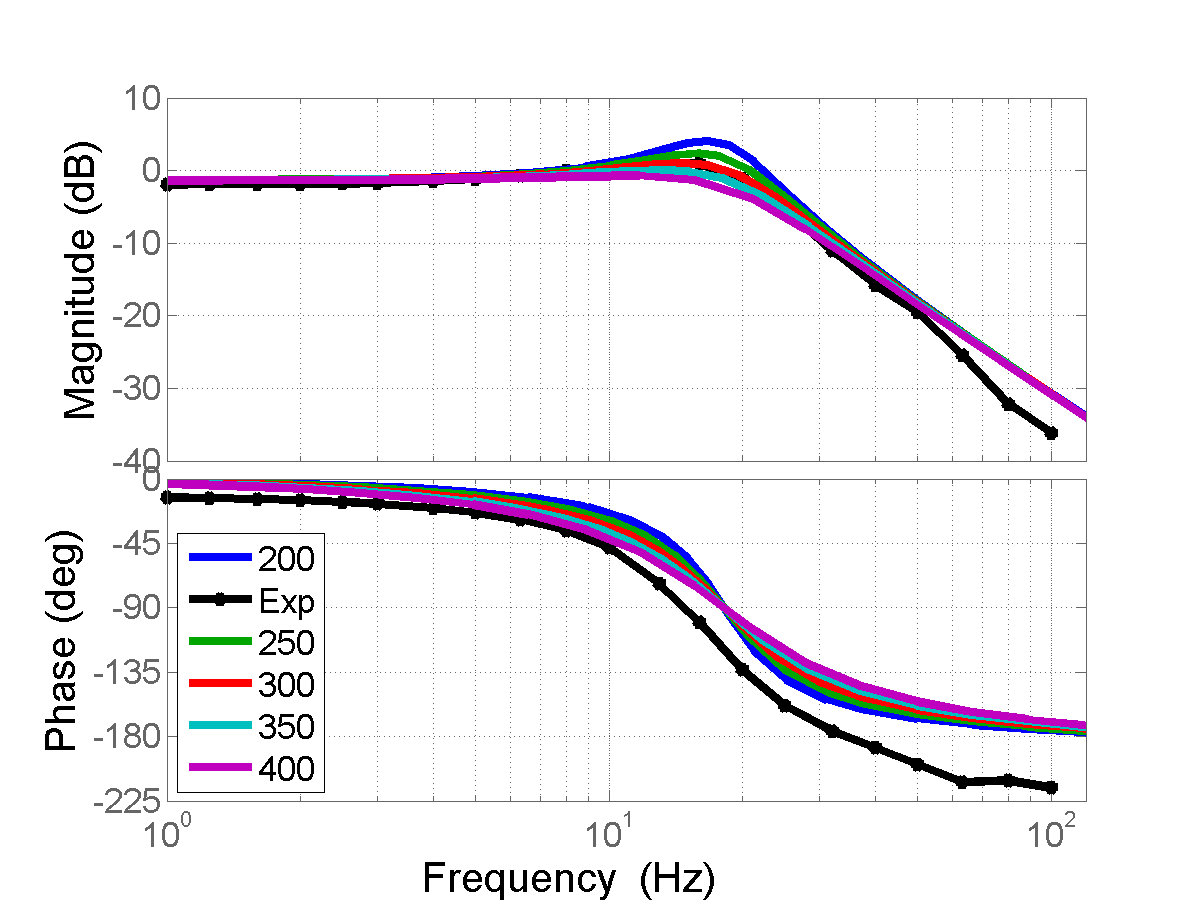
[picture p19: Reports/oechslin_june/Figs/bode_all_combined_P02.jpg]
	
	\caption{Bode plot comparison of experimental data of the P-controller and analytical transfer functions for several different $b_{sp}$.}
	\label{fig:bode_all_combined_P02}
\end{figure}

\begin{figure}[h!]
	\centering
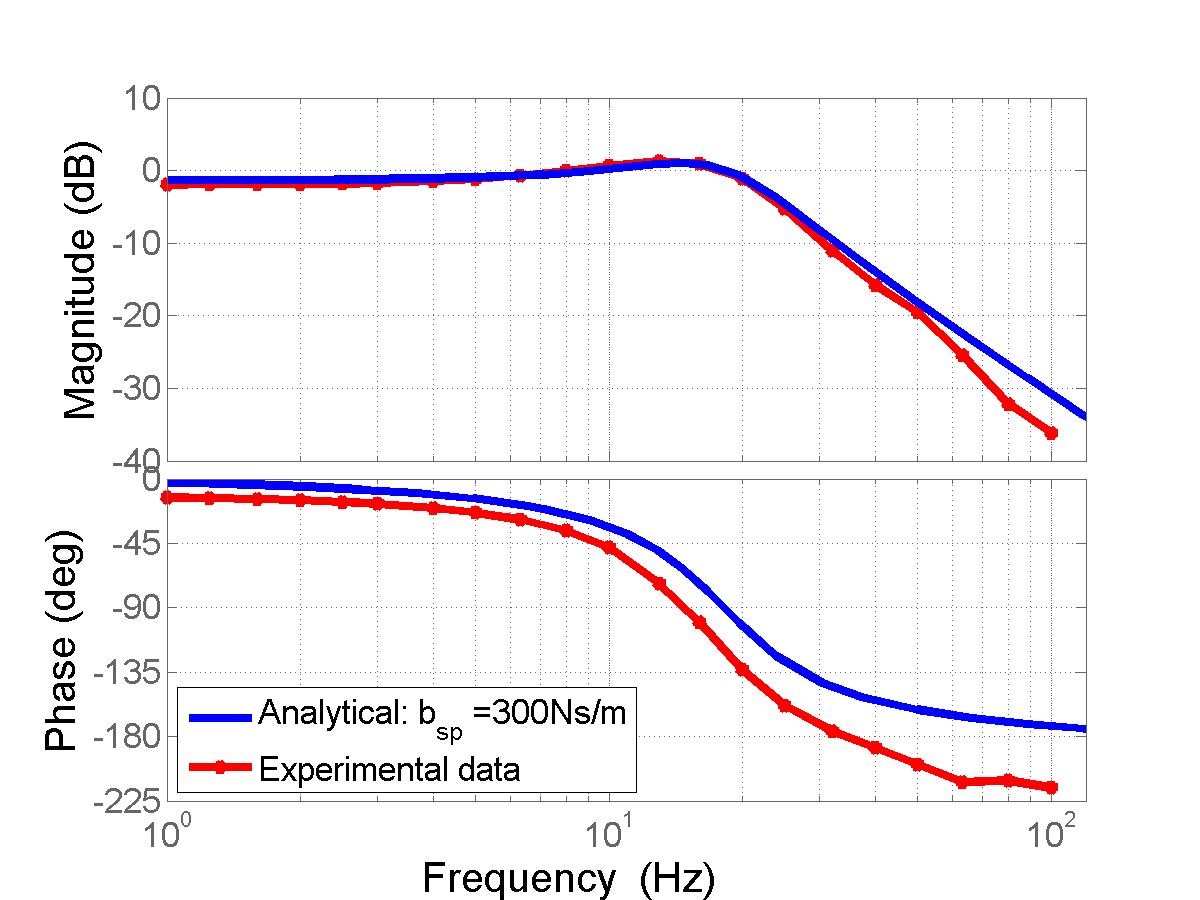
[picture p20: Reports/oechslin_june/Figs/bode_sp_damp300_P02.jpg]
	
	\caption{Bode plot comparison of experimental data of the P-controller and analytical transfer function for $b_{sp} = 300$Ns/m.}
	\label{fig:bode_sp_damp300_P02}
\end{figure}

%	\begin{figure}[h!]
%		\centering
%		\begin{subfigure}{.5\textwidth}
%			\centering
%			\includegraphics[width=0.6\linewidth]{Figs/bode_all_combined_P02}
%			\caption{Bode plot comparison of experimental data of P-controller and analytical transfer functions for several different $b_{sp}$.}
%			\label{fig:bode_all_combined_P02}
%		\end{subfigure}%
%		\begin{subfigure}{.5\textwidth}
%			\includegraphics[width=0.6\linewidth]{Figs/bode_sp_damp300_P02}
%			\caption{Bode plot comparison of experimental data of P-controller and analytical transfer function for $b_{sp} = 300$Ns/m.}
%			\label{fig:bode_sp_damp300_P02}
%		\end{subfigure}
%		%\caption{A figure with two subfigures}
%		%\label{fig:test}
%	\end{figure}

As it can be seen in figure \ref{fig:bode_sp_damp300_P02} there is a constant gain of $1$ for lower frequencies and a slight resonance top becomes visible around $18$Hz. The phase shift is of around $-210^\circ$ for the tested frequencies, and the lag does not increase more than $45 ^\circ$ for the frequencies of interest. Due to the setup constraints, the analytical results of higher frequencies have not been considered.

\subsection{Motor Comparison}
When one goes back to the experimental results where the two motors with different reduction gear ratios have been compared (previous report), %TODO make reference here, put up to date photos
one can conclude that the motor with the higher reduction ratio has a higher output force with a tradeoff of speed. Since one of the critical elements of the SEA system is its actuation speed, it is essential to push the boundaries as far as possible. However, the high gain frequency response in the experimental setup starts to drop at much higher frequencies than the actual operating frequency (which is given by the rather slow communication speed between the robot and the control device of $f_{op} \simeq 2-5$ Hz).\\
Due to the fact that even with the stronger reduction gear motor, the springs cannot be compressed to their limits, a higher possible output force has been favored and therefore the stronger motor seems more appropriate.

\subsection{Experimental PID Tuning}
At first, the Ziegler Nichols tuning method has been used to identify the PID gains for the setup. However, due to the non-linear behaviour, these gains resulted in a rather poor tracking performance of the reference signal.\\
Since an educated tuning of the gains is the very core problem of all control engineering, a lot of different approaches exist to find optimal or sub-optimal gain values. Given the complexity of the setup, it seemed reasonable to go for the simple trial and error approach, where the gains have been tuned and the tracking performance was shown in real-time. This approach led to the following gain coefficients:

%TODO discuss the fact of neglected efficiency, what is backdriveability exactly, redo bode plot with new pid settings 
\begin{figure}[h!]
	\centering
	\begin{tabular}{|l|c|c|}
		\hline
		Designator & Value & Unit \\ \hline \hline
		$K'_P$ & $47.6$ & [V/mm]\\ 
		$K'_I$ & $0.124$ & [V/mm/s]\\
		$K'_D$ & $247$ & [Vs/mm]\\
		\hline
	\end{tabular}
	\caption{Trial and error PID tuning.}
	\label{tab:trial_error_pid}
\end{figure}

\subsection{Tracking Behavior of the PID-controller}
The tracking behavior of the P-controlled setup can be seen in the following figures.
%show picture, explain problem of steady state offset, find PID values
\begin{figure}[h!]
	\centering
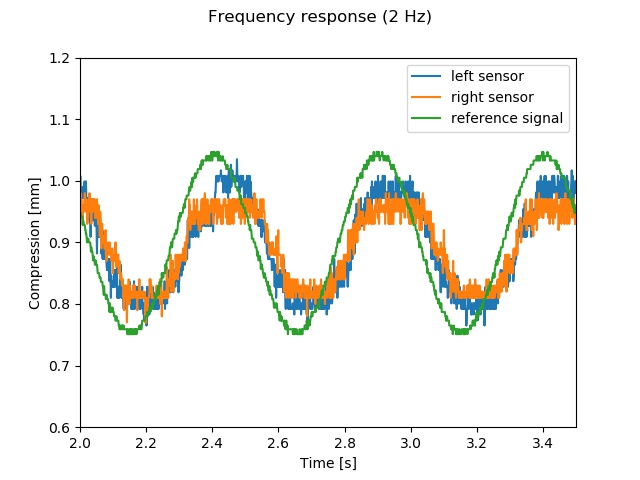
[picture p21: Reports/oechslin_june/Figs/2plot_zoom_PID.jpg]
	
	\caption{Tracking behavior of the PID-controller for $2$ Hz.}
	\label{fig:2plot_zoom_PID}
\end{figure}
\begin{figure}[h!]
	\centering
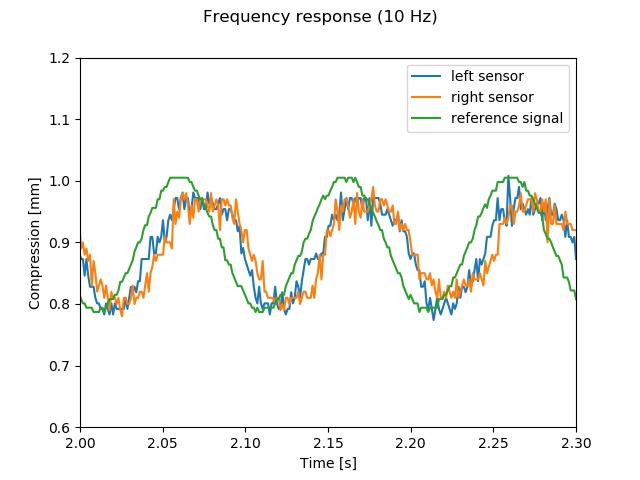
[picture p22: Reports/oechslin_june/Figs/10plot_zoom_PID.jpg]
	
	\caption{Tracking behavior of the PID-controller for $10$ Hz.}
	\label{fig:10plot_zoom_PID}
\end{figure}

\subsection{Comparison of Results - PID-controller and Experimental Data}
With the gains stated in table \ref{tab:trial_error_pid}, the frequency response can be measured again. This has been done for the left and right side, both using the motor with a reduction ratio of $n = 112$. The comparison between the analytical results from the mathematical model and the experimentally gathered data can be seen in figure \ref{fig:bode_sp_damp100_PID}.

\begin{figure}[h!]
	\centering
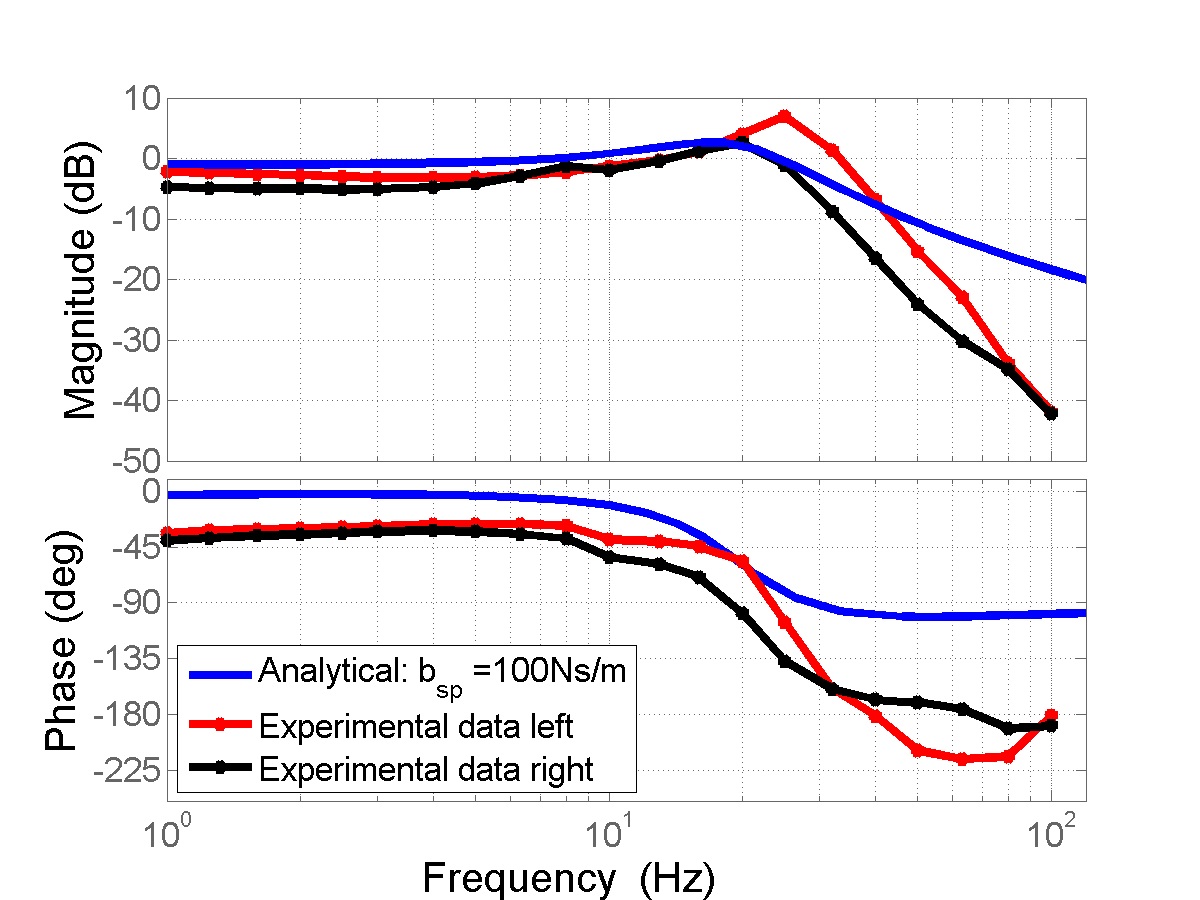
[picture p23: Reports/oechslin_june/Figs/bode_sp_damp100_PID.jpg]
	
	\caption{Bode plot comparison of experimental data of the PID-controller and analytical transfer function for $b_{sp} = 100$Ns/m.}
	\label{fig:bode_sp_damp100_PID}
\end{figure}

\section{Discussion}
\subsection{P-controlled Device}
As figure \ref{fig:bode_sp_damp300_P02} indicates, the results of the mathematical model seems to correspond with the experimental data. Furthermore, a damping coefficient of $b_{sp} = 300$ Ns/m could be identified. The tracking behavior of this P-controller was reasonable for lower frequencies, even though there was a slight steady-state offset. The constant phase-lag was very small for small frequencies and did not exceed $45^\circ$ for frequencies up to $10$ Hz. Even an approach of discretizing the analytical results did not yield a better match of the results. %TODO necessary to discuss this, or show the graph?
 
\subsection{PID-controlled Device}
When the PID-controller has been implemented, the difference between analytical results and the experiments was much bigger. First it was noteworthy, that the two motors showed a different behavior with the same gains. This might stem from several asymmetries in the setup. First of all and most importantly, the distance sensors are different, and have different threshold values. Also, the springs might not have been glued in a perfectly symmetrical manner. However, the noise characteristics of the sensors are in a similar order of magnitude and do not account for the differences here. Lastly, there are the mechanical aspects of how the motors have been screwed to the controller. Due to the high-frequency driving, the screws loosen from time to time, which can have a significant impact on the Bode plots. Furthermore, there might be a slight misalignment of the motor shaft axis and the guideway, which results in an opposing force.\\
Again, the discretization of the analytical transfer function did not yield a better match between the analytical and experimental data.\\
Judging from the frequency response seen in figure \ref{fig:bode_sp_damp100_PID} the tracking is relatively bad at low frequencies, not only because there is an attenuation, but also that the resonance top at higher frequencies quickly leads to saturation of the applicable motor voltage. In addition to this, the phase lag is much bigger and is already at least $45 ^\circ$ in the lower range of the bandwidth. This is due to the filters that have been used. The first filter is an RC-circuit that takes the PWM signal from the arduino and produces a more continuous voltage signal for the amplifiers. The cut-off frequency is $330$ Hz. The second filter is within the arduino code and is used to filter the measured distance. This filter was necessary to reduces the impact of noise amplification in the derivative part of the PID-controller. Three different filters with cut-off frequencies from $f_1 = 1.6$ Hz, $f_2 = 4.2$ Hz and $f_3 = 8.8$ Hz have been tested.

% talk about filter and filter impact, problem of discretization, results	

\section{Conclusion}
Given the results for the P-controller, one can assume that the mathematical model is correct. However, when one implements a PID-controller, a higher discrepancy between mathematical model and experimental data arises. Even though the parameters used in the mathematical model have been double-checked (such as the moment of inertia for example), its validity can be questioned.\\
From the two different implementations, the P-controller shows a better tracking behavior for the operational bandwidth.

\section{Outlook}
In the future, the P- and PID-controller shall be tested and a subjective measure of the feedbacks smoothness and transparency shall be reported.\\
A more thorough literature review shall be done to discuss the findings with existing papers.\\
A design-choice guide shall be created in order to facilitate future research for similar setups.

	%ここまで
}

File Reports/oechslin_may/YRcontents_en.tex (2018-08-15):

% Your name
\renewcommand{\YRname}{R. Oechslin}

% Your grade/post
\newcommand{\YRgrade}{M2}

% Submission date
\newcommand{\YRdate}{2018.Jun.04}

% Your research theme
\newcommand{\YRtheme}{Haptic Feedback Controller with Palm Pressurization}

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

% Main contents of your work
\newcommand{\YRachievement}{
	
	\section{Introduction}
	This report is the continuation of the first report about the project "Haptic Feedback Controller with Palm Pressurization". The last report has left off with the conclusion that the Arduino had a limited operating frequency and that the gathered data was not reliable enough, since not the whole region of interest in frequency could be covered. First, the idea was to use an mbed and program it to be able to replace the Arduino. However, with a few tricks %TODO explain what I did with prescaler and such
	it was possible to reduce the time of some commands to a minimum to stay at an operating frequency of $1$kHz. \\
	This report explains the setup and states the result for the adapted controller and provides a somewhat short explanation and discussion of the gathered data.
	
	\section{Experiment and Data Gathering}
	The setup can be seen in figure \ref{fig:setup_annotated}.
	\begin{figure}[h!]
		\centering
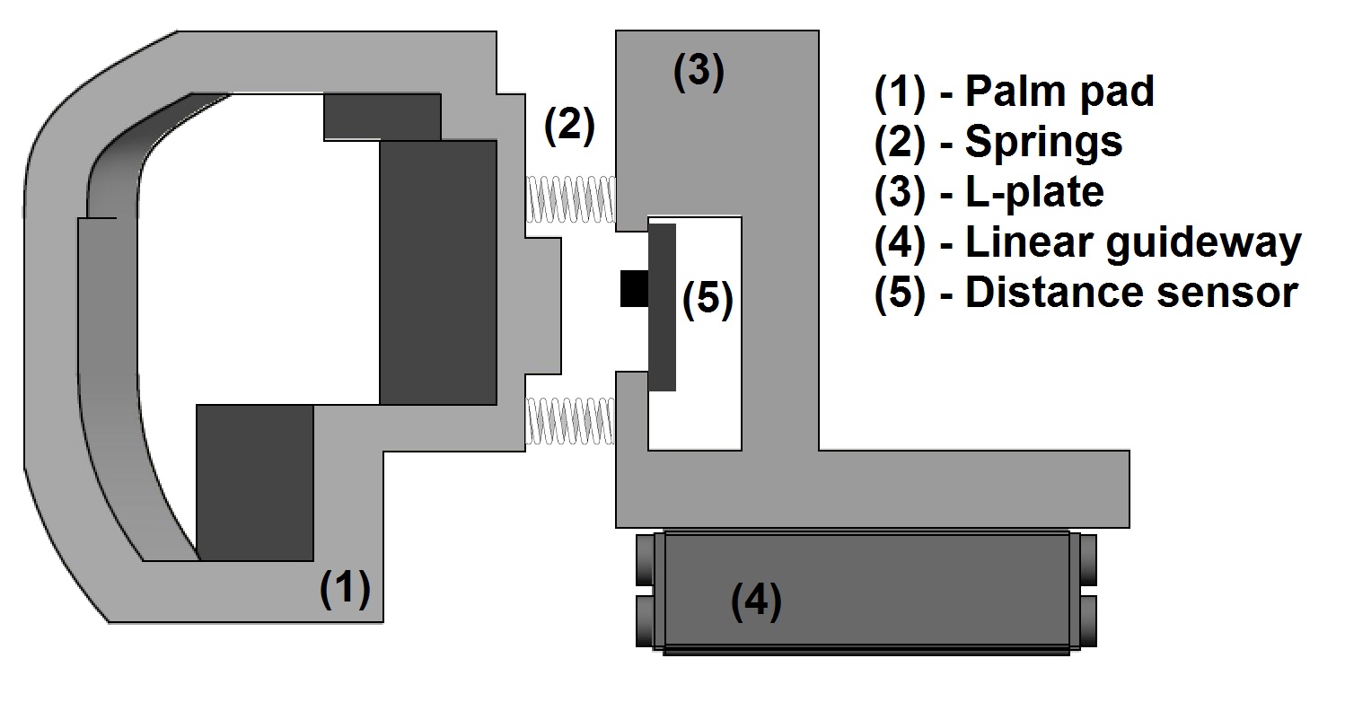
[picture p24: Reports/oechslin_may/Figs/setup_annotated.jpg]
		
		\caption{Schematic of the spring system setup.}
		\label{fig:setup_annotated}
	\end{figure}
	For this experiment, a total of four springs, arranged symmetrical on the palmpad have been used. The springs have a spring constant of $k_s = 1.5$N/mm which corresponds to an equivalent spring constant of $k_{eq} = 6$N/mm. They are distributed around the palm pad, where in their middle a distance sensor (called photoreceptor) has been attached, to measure the distance between the L-plate and the palm pad. It therefore measures the compression of the springs, which can be related to the output force by Hooke's law as:
	\begin{equation}
		F = k_{eq}x 	
	\end{equation}
	
	\subsection{Setup}
	In this experiment a thorough frequency response analysis shall be done on the controller. On the left-hand side the motor with a reduction ratio of $33:1$ has been used, whereas for the right-hand side, the motor has a reduction ratio of $112:1$. \\
	A reference signal is fed into the Arduino, which then controls the motors to match the compression of the springs with the reference. The operational distance of the photoreceptor to the palm pads is $2$ to $4$mm which lies within the more sensitive region of the sensor.
	
	\subsection{Control Scheme}
	The reference signal is given by the Function Generator SG-4115. This generator has an intrinsic output impedance of $50$Ohm. This means, that it expects to have a device connected to it with the same value as input impedance. If this is the case, these two elements form a simple voltage divider and only half of the voltage is applied to the target device. However, this is not the case for the Arduino, since it has a considerably higher input impedance. Therefore, the settings made on the function generator result in double the voltage on the Arduino. From this point on, this issue shall be neglected and all future voltage indications refer to the voltage level as seen by the Arduino.\\
	The function generator produces a sine wave between $0$ and $5$V with a frequency ranging from $1$ to $100$Hz. The Arduino reads this voltage and controls the motor to have a proportional spring compression accordingly. In this case $0$V as reference signal is $0\%$ compression and $5$V corresponds to $100\%$ compression. The control scheme of this setup can be seen in figure \ref{fig:frf_measure_points}.
	\begin{figure}[h!]
		\centering
		
		\caption{Control scheme for the frequency response analysis.}
		\label{fig:frf_measure_points}
	\end{figure}
	In this case the counteracting force from the user is infinite, since the palm pads have been blocked by a wall.
	
	\subsection{Photoreceptor Circuit}
	The circuit of the photoreceptor can be found in figure \ref{fig:tpr105_circuit}. The components chosen are the TPR-105 for the sensor, $R_1 = 330\Omega$ and $R_2 = 27k\Omega$.
	
	\begin{figure}[h!]
		\centering
		
		\caption{Photoreceptor circuit.}
		\label{fig:tpr105_circuit}
	\end{figure}
	The photoreceptors working principle is based on detecting the amount of reflected light. This controls the base current $i_B$ of the transistor in the schematic. This base current then determines the collector current $i_C$. Specific to this setup, the distance and therefore the output force controls the amount of light that is reflected on the wall of the palm pad. Therefore, we have:
	\begin{equation}
	F_{output} = k_{eq} \Delta x \propto i_B
	\end{equation}
	\begin{equation}
	i_C = h_{FE} i_B
	\end{equation}
	\begin{equation}
	V_{out} = V_{CC} - h_{FE} R_2 i_B = V_{CC} - K R_2 \Delta x
	\end{equation}
	Where $h_{FE}$ is the forward current gain and $K$ is a constant given by $h_{FE} k_{eq}$.
	
	The two resistor values have been empirically found to have the highest sensitivity but not saturating the measurement. The sensitivity decreases with a smaller resistor, since at a certain point, the Arduino cannot detect a change in voltage anymore. Saturation occurs, when the value of $R_2$ is too high.
	
	\subsection{Identification of Operational Range (Photoreceptor)}
	To find the receptor values at maximum compression of the springs, a simple test has been made, where one time $0$V has been applied to the motors, and another time $20$V has been applied. This $20$V value is within a safety margin of the maximum applicable voltage given by the datasheet of the motors. The result can be seen in figure \ref{fig:max_volt_applied_plot}.
	
	\begin{figure}[h!]
		\centering
		
		\caption{Operational range of photoreceptor with springs at rest and in full compression.}
		\label{fig:max_volt_applied_plot}
	\end{figure}
	
	The values that have been found to be the limiting values are resumed in table \ref{tab:oper_range_PS}.
	
	\begin{figure}[h!]
		\centering
		\begin{tabular}{|l|c|c|c|c|c|}
			\hline
			& Sensor reading & Distance & Sensor reading & Distance & Max output  \\
			& MAX (rest) & (rest) & MIN (compression) & (compression) & force \\ \hline \hline
			Left side & 830 & 2.35mm & 650 & 4mm & 9.9N \\ \hline
			Right side & 870 &2.2mm & 700 & 4mm & 10.8N \\ \hline
		\end{tabular}
		\caption{Identified operational range for the photoreceptors in the PlayStation controller.}
		\label{tab:oper_range_PS}
	\end{figure}
	
	Using these values, the photoreceptor measurements can be mapped to this range with an 8-bit value. This means that $0$ is no compression and $255$ is fully achievable compression.
	
	\section{Frequency Response Analysis}
	To conduct the frequency response analysis in a meaningful environment, the controller has to be tested under conditions close to the operational ones. To be able to control the distance between the palm pads and the L-plates, and therefore the compression ratio of the springs, the palm pads have been blocked mechanically. With the wave generator producing the reference signal, the Arduino controlled the motors to match the compression with the reference. Figures \ref{fig:1plot_zoom} to \ref{fig:100plot_zoom} show some testcases.

	\begin{figure}[!htb]
		\minipage{0.32\textwidth}
		
		\caption{1 Hertz}\label{fig:1plot_zoom}
		\endminipage\hfill
		\minipage{0.32\textwidth}
		
		\caption{12.6 Hertz}\label{fig:12.6plot_zoom}
		\endminipage\hfill
		\minipage{0.32\textwidth}%
		
		\caption{100 Hertz}\label{fig:100plot_zoom}
		\endminipage
	\end{figure}
	With these signals one can calculate the amplification factor between the reference signal and the output signal, as well as the phase shift.

	\subsection{Sinewave Fitting}
	As described in this example\cite{exnumerus2010}, one can fit a sinewave with the linear least square method to the samples. For finding the amplitude the second norm%TODO why not RMS as explained in slides_frf_and_bode_plots.pdf
	 has been used. This function returns the phase, amplitude and the bias. In this case, the difference in phase between input and output, as well as the amplitude ratio is needed in order to plot a Bode diagram.
	
	\subsection{Bode Diagram}
	The results of the frequency response analysis are shown in figures \ref{fig:bode_left} and \ref{fig:bode_right}.
	
	\begin{figure}[!htb]
		\minipage{0.48\textwidth}
		
		\caption{Left-hand side, Motor reduction ratio $33:1$}\label{fig:bode_left}
		\endminipage\hfill
		\minipage{0.48\textwidth}
		
		\caption{Right-hand side, Motor reduction ratio $112:1$}\label{fig:bode_right}
		\endminipage\hfill
	\end{figure}

	For the left-hand side, a resonance top at around $13$Hz can be found, with a gain of roughly $-12$dB for lower frequencies. At higher frequencies a slope of roughly $-26$dB/dec has been calculated. For doing so the values in the range of $50$Hz and $100$Hz have been used. The phase shifts from $-25^\circ$ to $-222^\circ$, a total shift of roughly $200^\circ$.\\
	For the right-hand side, no resonance top is visible, and a constant gain of roughly $-6$dB for lower frequencies can be identified. At higher frequencies a slope of roughly $-30$dB/dec has been calculated. Again using the values in the range of $50$Hz and $100$Hz. The phase shifts from $-25^\circ$ to $-223^\circ$, a total shift of roughly $200^\circ$.
	%in slides_frf_and_bode_plots.pdf slide 27 suggests that the pole is stable since it goes from 0 to -180
	
	\section{Discussion}
	As it can be seen in figues \ref{fig:1plot_zoom} to \ref{fig:100plot_zoom} the signal is not followed very smoothly. For one, the magnitude ratio even at low frequencies is at roughly $0.5$. This shows that the proportional gain is too low. This would not only lift up the curve indicated in the Bode diagram and shift it towards higher frequencies (to the right). Another important aspect is the saturation behavior of the right motor. The origin of this effect  needs to be investigated in more detail.\\
	From the Bode diagrams one can conclude several things. First of all, the gain magnitude at lower frequencies should be around $0$dB to have perfect following of the reference signal. This can be influenced by tuning the proportional value of the controller.\\
	Second, the two motors show different characteristics. While the weaker motor (left-hand side) shows a resonance top around $13$ Herz, the stronger motor has no such behavior. In order to have a more linear system, it is therefore favorable to use the stronger motor for this spring system.\\
	Furthermore, the first pole of the system can be found around $13$ Herz. The communication frequency between robot and graphical user interface is suggested (according to the datasheet of the robot) to be between $1$Hz and $5$Hz. This shows that the series elastic actuator system as it is implemented in this experiment, is not the limiting factor in the robotic system.\\
	When one wants to determine the order of the system, one can look at the slope at the tail of the magnitude curve in the Bode plot. In our case they are $-26$dB/dec and $-30$dB/dec for left and right respectively. Since the slopes can only be a multiple of $20$dB/dec, it can be concluded, that the $2 \xi \omega _0$ term from equation \ref{eq:transfer_fn_2nd_order} has a non-negligible influence at the tail of the Bode plot.
	The equation of a second order transfer function is as follows:
	\begin{equation}
		H (s) = \frac{\omega _0^2}{s^2 + 2 \xi \omega _0 s + \omega _0^2}
		\label{eq:transfer_fn_2nd_order}
	\end{equation}
	Therefore one should also have a look at the phase lag diagram. The phase shift of roughly $180^\circ$ suggests a second order transfer function.
	
	The only thing that might risk the reliability of the Bode diagrams is the fact that the output signal has shown to be electrically interfering with the input signal. This most probably comes from the fact that the output impedance is too high.

	\section{Conclusion}
	The Bode diagrams show promising results. This is a first hint that the implementation of the series elastic actuators is not slowing down the system, since the bottleneck is given by the robot GUI communication link.\\
	
	\section{Outlook}
	The input signal is interfering with the output signal on the Arduino. Therefore it is necessary to investigate its impact by implementing a voltage follower to reduce the output impedance.\\
	A theoretical model shall be calculated to take into account the different aspects and parameters of the setup. The goal is to come up with a precise model to simulate different parameter settings, such as equivalent spring constant, motor parameters or operating frequency.

	%ここまで
}

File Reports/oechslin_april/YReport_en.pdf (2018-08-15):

# Monthly Report (Yamamoto Lab.)

date: 2018.Apr.27
Author: R. Oechslin (M2)

Research theme: Haptic Feedback Controller with Palm Pressurization

— Research Plan —

Term \Month | 2 | 3 | 4 | 5 | 6 | 7 | 8 | 9 | 10 | 11 | 12 | 1

Literature review
Design PlayStation Controller
Test PlayStation Controller
Design Pilot Controller
Test Pilot Controller

Program mbed device
Redo experiments
Make third controller?
Analyze data and compare
Write Thesis

— Work Contents —

### 1 Introduction

A lot of research on haptic feedback in handheld devices has been conducted, not only with force feedback ([Prattichizzo et al., 2012], [Schoonmaker and Cao, 2006]), but also with pressure stimulation ([Asada T., 2016], [Nakamura et al., 2016]). The major applications for such haptic feedback devices can be found in (minimally invasive) surgical teleoperated medical systems ([van den Bedem et al., 2009], [Enayati et al., 2016], [Tavakoli et al., 2004], [Nisky et al., 2011]), mobile augmented reality ([Bermejo and Hui, 2017], [Hasegawa et al., 2006]) and teleoperated robotic systems (for example in space) [Christiansson, 2007]. However this research project focuses on implementing a feedback on a handheld controller for a non-specified group of grounded wheeled robots. The controller uses pressurization feedback as a substitution for force feedback to give an intuitivefeeling about the intrinsic state of the robot. The tests of the controller shall be made on the commercially available crawler robot from topy 1 using two tracks as means of transportation.

As an initial approach and to be consistent with the previous research in this area [Asada, 2016] the robots orientation (pitch and roll angles) have been taken as state of interest. As an alternative measure, the current in the two crawler motors can be fed back to the user, to have a rough idea of used energy and to make it detectable if the robot is being stuck or blocked somewhere.

Project Description and Status Quo in the Beginning of the Project
The handheld controller that has been designed at Yamamoto’s lab in 2016 and 2017 uses voice coil motors (VCMs) for the feedback. The disadvantage of these motors is that a constant voltage has to be applied to maintain a constant force. This leads to an energy-inefficient system

1
http://www.topy.co.jp
– 1 – | Author: R. Oechslin

and produces a lot of extra heat. The testing environment for this controller consists in a Unity program that lets the user control a tank with crawlers in an artificial landscape. When one drives over the hills and smaller bumps, the user feels the magnitude of the tilt (orientation angles roll and pitch) as a pressure on the palms.
The goal of this work is to replace the VCM by a set of series elastic actuators (SEAs). These SEAs should have a low backdriveability, such that the setup can maintain a feedback force without constantly applying a voltage. Different types of models using SEAs shall be prototyped and tested on a real robot (topy). Furthermore, different feedback laws shall be implemented and tested to find the most intuitive feedback for the state of the robot.

### 2 Design and Analysis

Series Elastic Actuators
The principle of series elastic actuators is relatively simple. The concept is explained in [Pratt and Williamson, 1995] which also mentions a more accurate and stable force control and the possibility of energy storage. A thorough study of an SEA design and its analysis has been made in [Junior et al., 2016], stating that the most important parameter in the system is the spring constant. Therefore, springs with several different spring constants have been used for the analysis of this research project.
In this study, two different SEA designs have been implemented and tested. The first design is based on a linear movement (constrained by a linear guideway), where the rotary motion of the motor is driving a lever, pushing the carriage back and forth. For more details, see figure 3.
The second design is an approximated linear motion, due to a very large lever (rotational-L) actuated by a cam principle.

Design of the PlayStation Controller
The first design of the haptic feedback controller has been partially inspired by the existing design and partially by the commercial controllers of PlayStation. The controller can be seen in figure 1.


Figure 1: 3D model of the PlayStation controller.

This design of the controller aims at having a natural position for the hands, such that the user

Author: R. Oechslin | – 2 –

can hold the controller for a long time without having the hands in an awkward position. As it can be seen in the figure, the palm pads that transmit the feedback pressure to the palms are not directed perpendicularly towards the user, but rather outwards at a certain angle (refer to figure 2). This can be seen as a drawback, since the user is expected to have the most intuitive feeling with a feedback opposing the driving direction (ie. perpendicular).


Figure 2: 3D model of the controller and the feedback direction indication.

The dimensions of the controller are 220mm in length, 110mm in width and 70mm in height. The controller is unusually thick due to the feedback actuation design. This actuation design can be seen in figure 3. The motor shaft is rotating a clamp link which is attached to a 3D-printed part, called connecting link. This 3D-printed part is attached to the carriage, an also 3D-printed part called L-plate, and is screwed to the linear guideway. The L-plate is connected via a set of springs (of variable spring constants) to the palm pad, thus making it an SEA. The linear guideway keeps the palm pad in a linear motion.


Figure 3: Actuation system with legend.

The legend refering to the actuation system in figure 3 is as follows:

- (1) : Palm pad
- (2) : Photoreceptor
- (3) : L-plate
- (4) : Connecting link

- (5) : Clamp link
- (6) : Motors
- (7) : Linear guideway
- (8) : Springs

Design of the Pilot Controller The 3D model of the left-hand side pilot-based controller can be seen in figure 4. To see the inside of the controller, the cover has been removed. To assemble it three sets of screws and nuts are necessary, making it easy to assemble and take apart. Also, this design is smaller in volume than the PlayStation controller. It is therefore more slender, cheaper and faster to manufacture.


Figure 4: 3D model of the left-hand side controller with a removed cover.

In this design, the feedback motion is perpendicular towards the user and opposing the direction of motion. However, there is a slight angle at which the force is acting, due to the rotational design in the controller. But due to the large lever, this effect can be neglected. The actuation principle is based on a simple cam disk that directly pushes the rotational-L. For this design, the motors with a higher reduction gear ratio have been foreseen.

Test Environment and Programs
To test the controller, it was necessary to write a properly working environment. The topy robot is communicating via a wireless serial link. It has a prespecified communication message that consists in 70 bytes for sending from the robot to the PC and 44 bytes for message to receive. These messages include the bytes reserved for proper starting and ending as well as the checksum. It was thus necessary to write an application that reads out the position of the two joysticks (basic potentiometers principle) and construct a message including these joystick values as speed reference for the robot. Then the message has to be sent over the wireless serial link to the robot and the answer has to be received. The important sensor readings (inclination, current in the crawlers, passed time and battery level) have to be read out and a feedback according to the chosen feedback law has to be sent to the motors.
For this purpose, the programming language processing 2 has been used to create a graphical user

interface and to establish the serial connection. For low-level motor control purposes an Arduino Uno has been used. The parameters that can be set for testing purposes can be seen in table 5.

2
https://processing.org/

Setting | Value | Units
Baud rate for robot serial link | 9600 | [bps]
Baud rate for Arduino serial link | 9600 | [bps]
Update rate of the processing GUI | 5 | [Hz]
Update rate of the Arduino motor controller (in theory) | 200 | [Hz]
Update rate of the Arduino motor controller (in practice) | 170 | [Hz]
Max voltage for motor | 20 | [V]
Feedback resolution | 5 out of 255 | [-]
PWM frequency | 31372.55 | [Hz]
Proportional motor gain | 1.5 | [-]
Integral motor gain | 0.0 | [-]
Derivative motor gain | 0.0 | [-]
Feedback filter | 50 | [%]
Left photoreceptor MIN value | 500 | [-]
Left photoreceptor MAX value | 770 | [-]
Right photoreceptor MIN value | 680 | [-]
Right photoreceptor MAX value | 770 | [-]

Figure 5: Software parameters.

GUI in Processing

The graphical user interface shows the current feedback method as well as the magnitude. It also indicates which driving direction (forward, backward or halt) is sent to the robot. Since there is no control of the battery charge in the robot, it sends battery information in its message to the PC. The processing program reads out the charge of the battery and warns the user if it is too low. It stops the program, if the battery state is critical. The feedback method can be changed by a mouse-click anywhere in the window. The GUI can be seen in figure 6.


Figure 6: Graphical user interface written in processing.

This application handles the messages sent to and from the robot.

Control Scheme

The control scheme is based on a simple proportional controller. The scheme can be seen in figure 7. In the test setup the reference signal distref is given by the sinusoidal function generator.

In the operational mode, this corresponds to the target output force, also called the haptic feedback force that should be felt by the user. Ideally, this shall be a function of orientation (roll and pitch) as well as the current in the two crawlers.


Figure 7: Control scheme for the haptic feedback system.
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

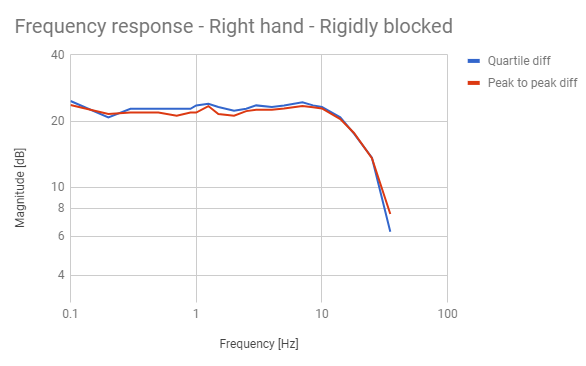
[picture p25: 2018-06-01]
Reports/oechslin_april/Figs/freq_resp_right_hand_rigid_experim1.png

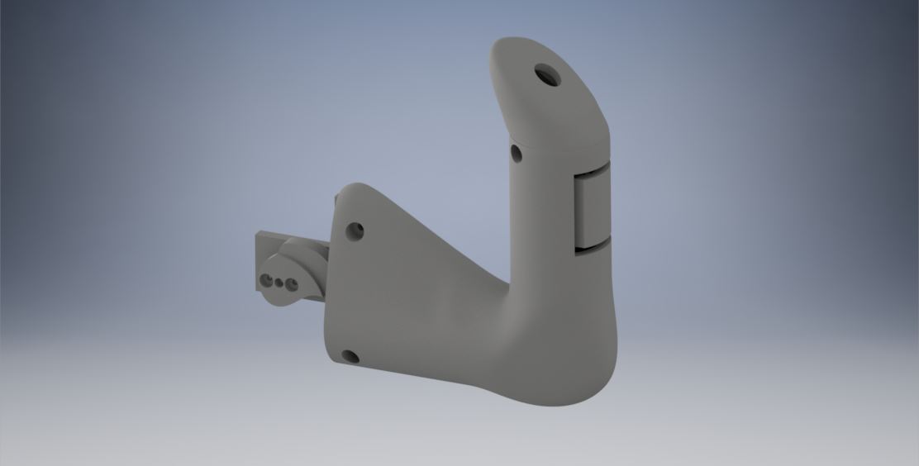
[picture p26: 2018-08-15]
3D designs/Yoke Controller/figures/left_hand_joystick_cam_rend.jpg

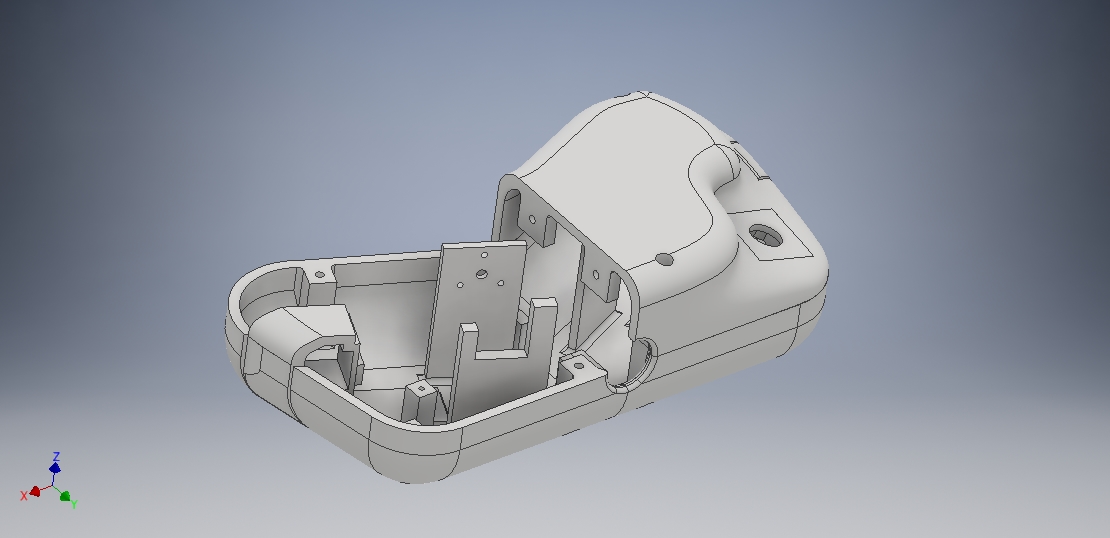
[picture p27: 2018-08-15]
3D designs/Game Controller/figures/PS_controller_smaller_open.jpg

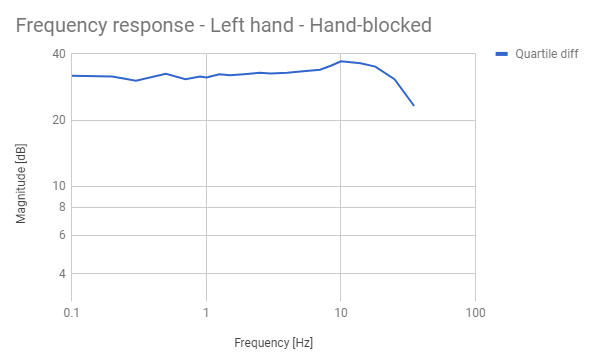
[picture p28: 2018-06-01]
Reports/oechslin_april/Figs/freq_resp_left_hand_handblocked_experim1.png

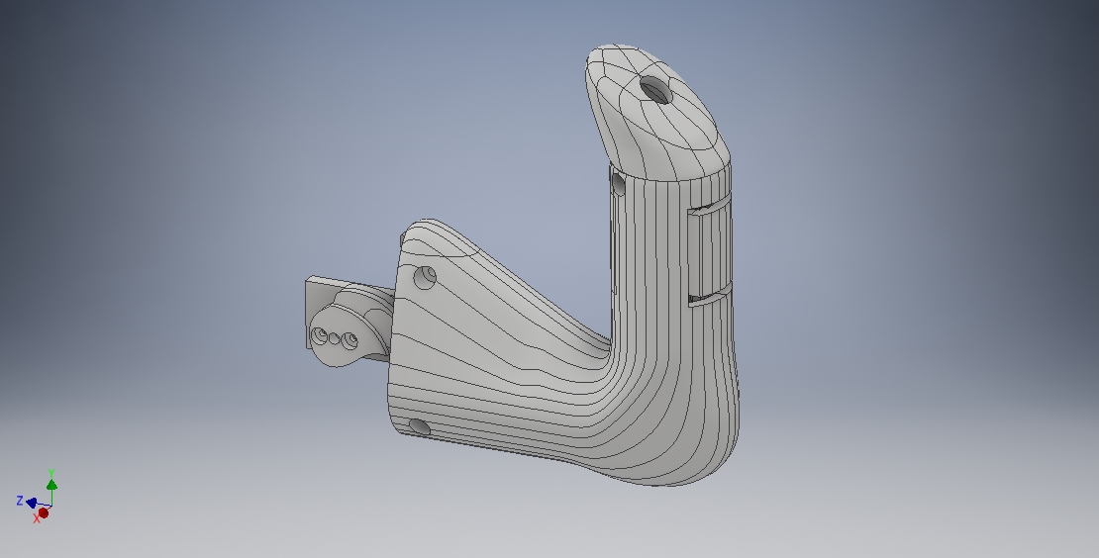
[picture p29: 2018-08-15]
3D designs/Yoke Controller/figures/left_hand_joystick_cam.jpg

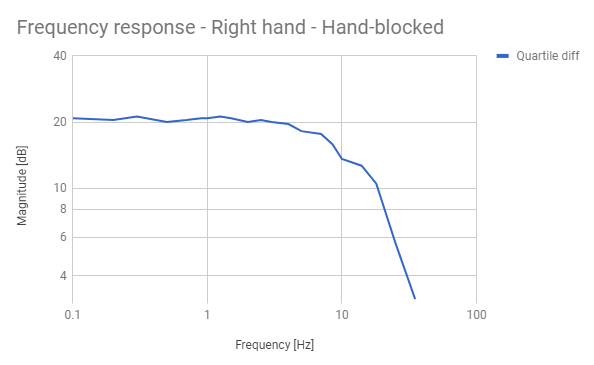
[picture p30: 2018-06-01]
Reports/oechslin_april/Figs/freq_resp_right_hand_handblocked_experim1.png

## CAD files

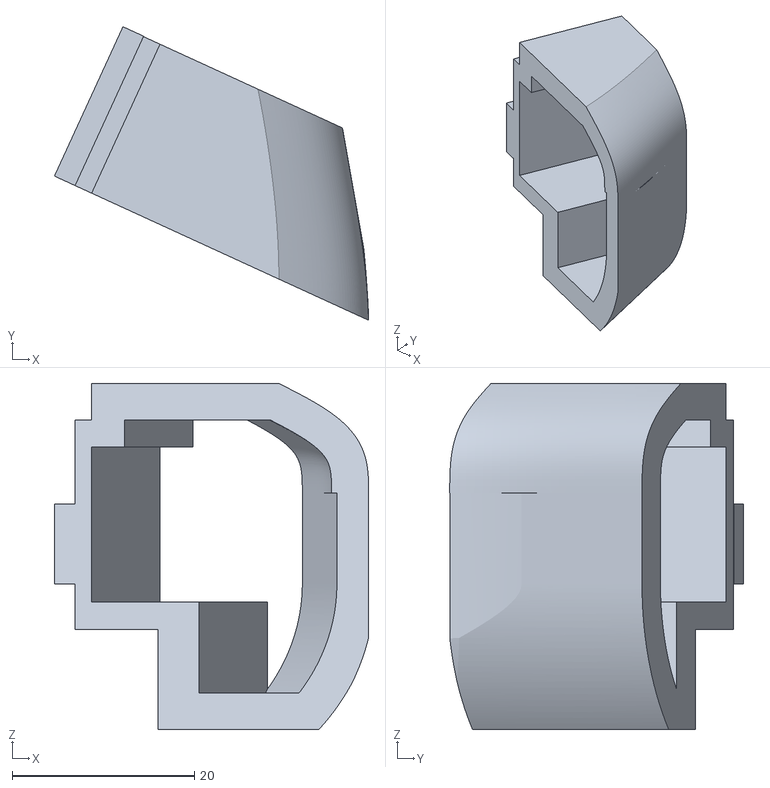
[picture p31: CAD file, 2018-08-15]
3D designs/Game Controller/printable/R_palm_pad.stl
34.5 x 32.2 x 38.0

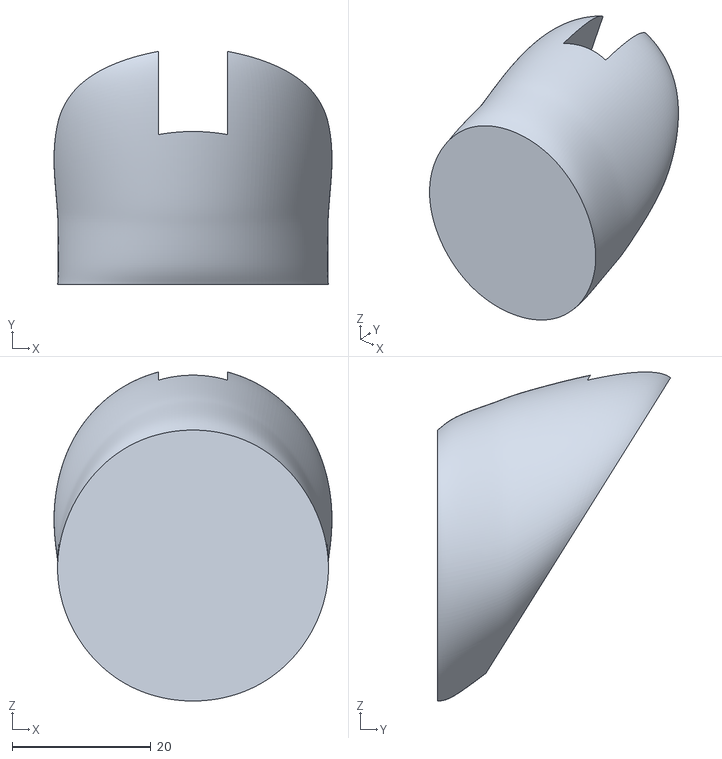
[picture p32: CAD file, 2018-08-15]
3D designs/Yoke Controller/printable/joystick_mount.stl
40.1 x 33.6 x 47.5

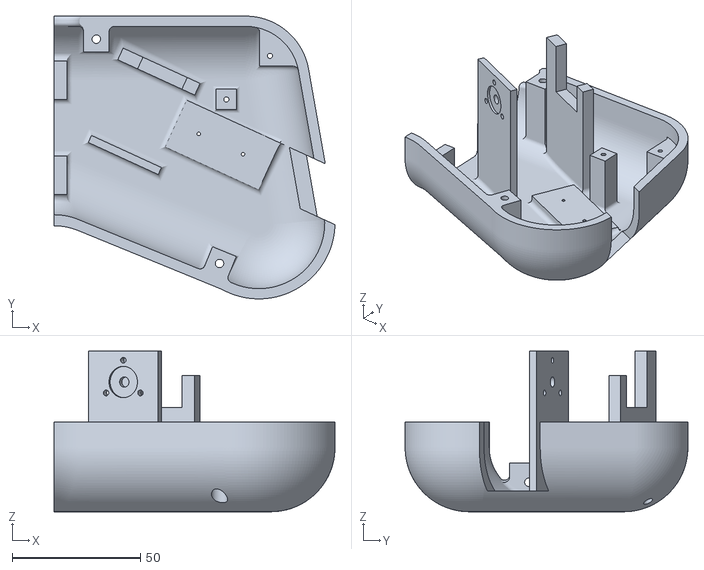
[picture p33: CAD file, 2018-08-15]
3D designs/Game Controller/printable/R_base.stl
109.6 x 110.3 x 62.6

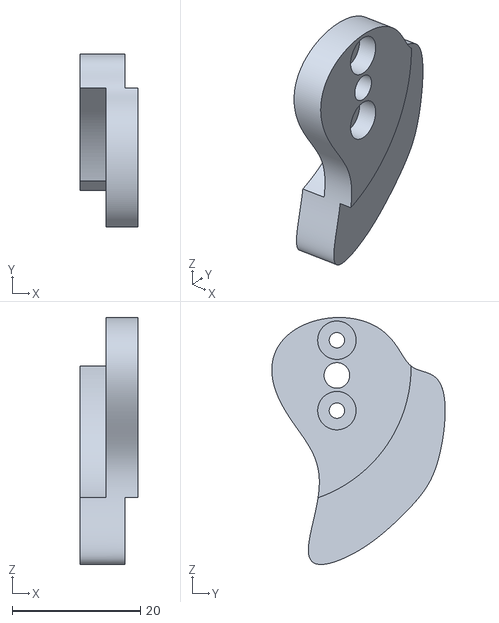
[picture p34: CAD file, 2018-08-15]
3D designs/Yoke Controller/printable/Rotation_cam.stl
9.00 x 27.1 x 38.6

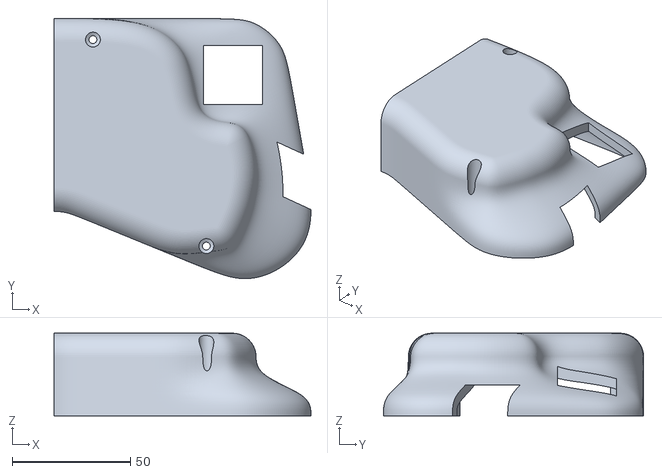
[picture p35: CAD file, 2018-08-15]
3D designs/Game Controller/printable/R_cover.stl
108.9 x 110.3 x 35.0

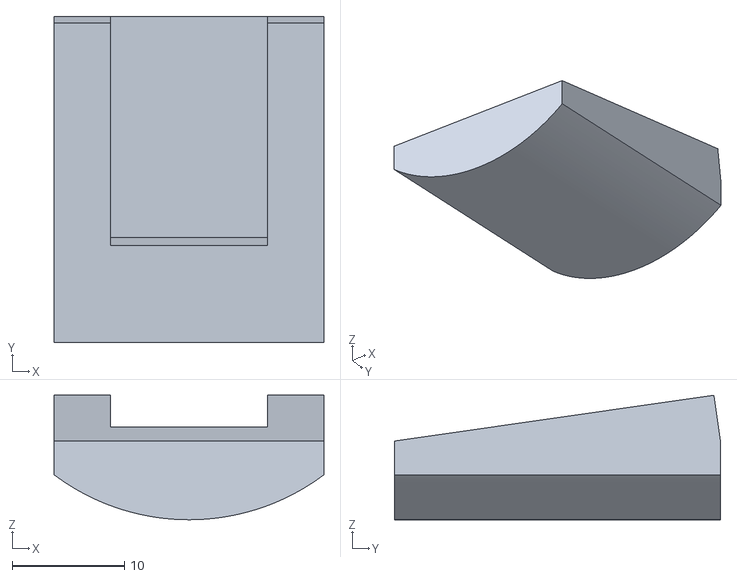
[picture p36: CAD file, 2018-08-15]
3D designs/Yoke Controller/printable/Palm_pad.stl
24.0 x 29.0 x 11.1

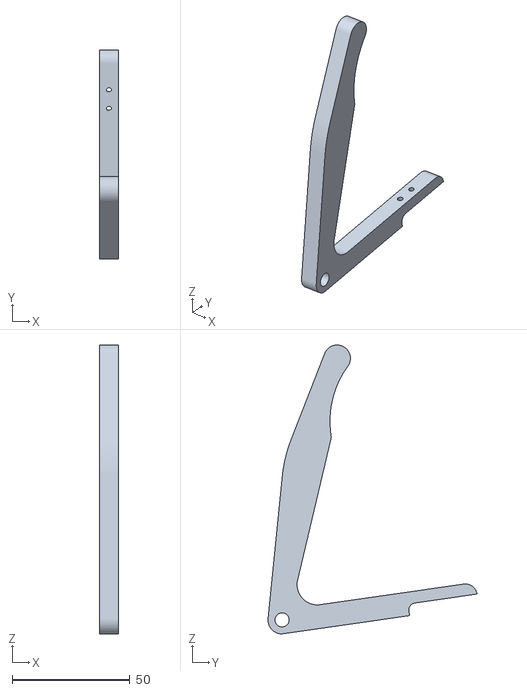
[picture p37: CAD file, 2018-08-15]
3D designs/Yoke Controller/printable/rotation_L.stl
8.00 x 88.9 x 122.9

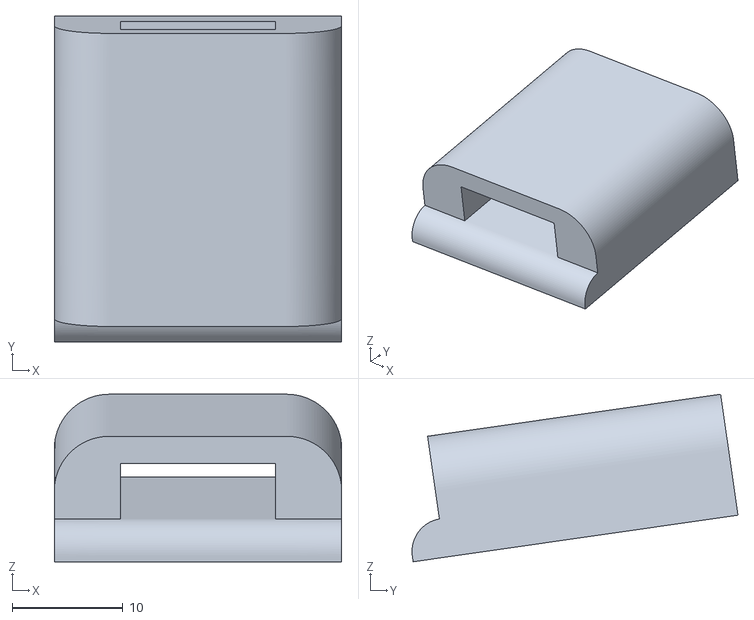
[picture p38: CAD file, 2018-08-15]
3D designs/Yoke Controller/printable/Spring_plate.stl
26.0 x 29.5 x 15.2

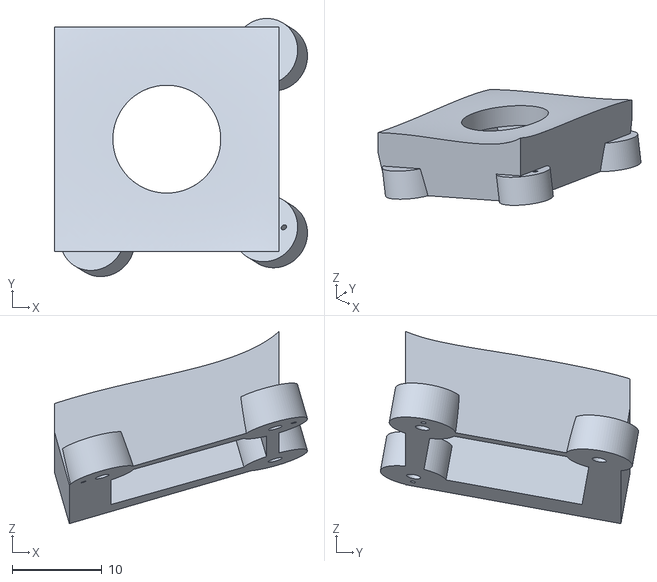
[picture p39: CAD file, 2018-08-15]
3D designs/Game Controller/printable/L_js_mount.stl
28.2 x 28.7 x 21.4

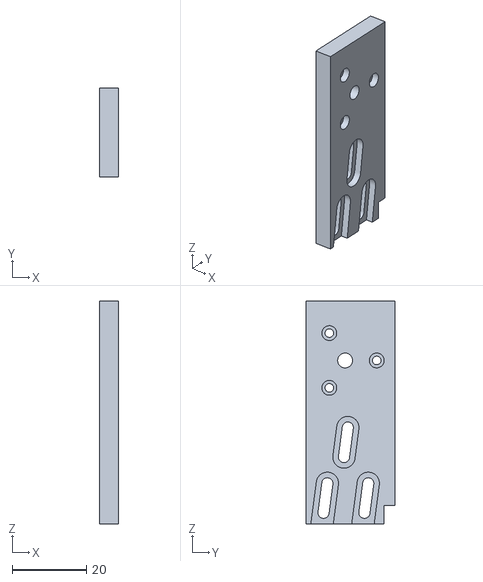
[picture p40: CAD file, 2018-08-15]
3D designs/Yoke Controller/printable/Motor_plate.stl
5.00 x 24.0 x 60.0

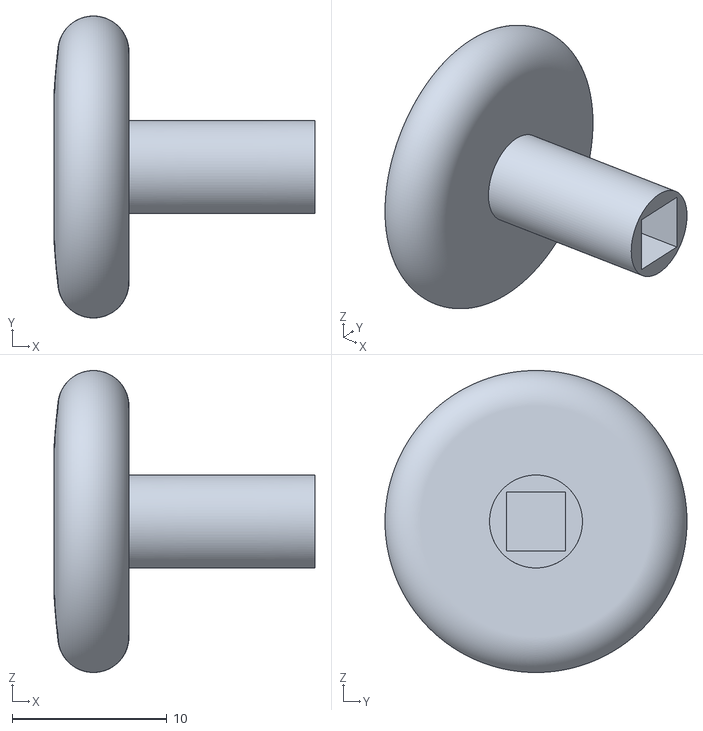
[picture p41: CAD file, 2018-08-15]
3D designs/Game Controller/printable/js_nibble.stl
16.8 x 19.5 x 19.5

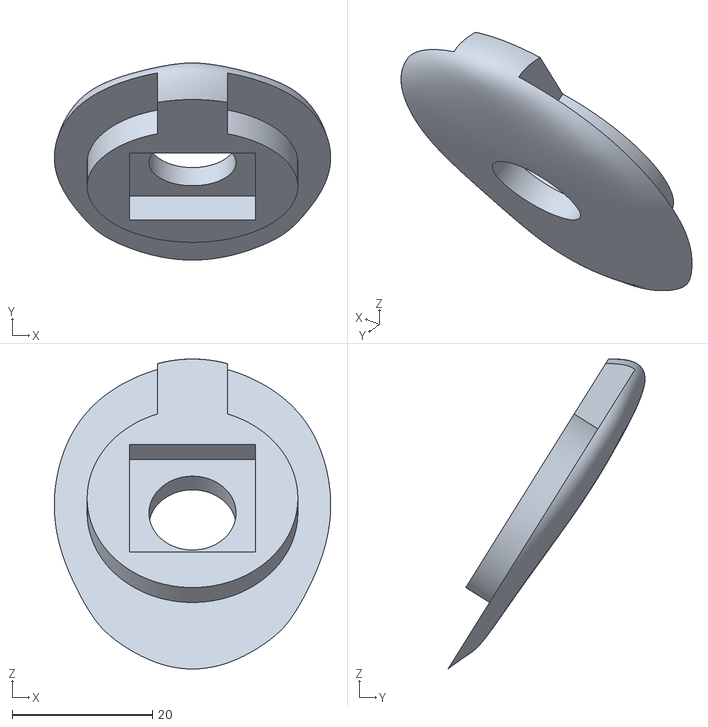
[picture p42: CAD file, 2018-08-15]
3D designs/Yoke Controller/printable/joystick_cap.stl
39.4 x 28.1 x 44.1

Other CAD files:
3D designs/Game Controller/drawings/Game Controller.dwg
3D designs/Yoke Controller/drawings/Yoke Controller.dwg
3D designs/Game Controller/printable/L_palm_pad.stl
3D designs/Game Controller/printable/L_cover.stl
3D designs/Game Controller/printable/R_js_mount.stl
3D designs/Game Controller/printable/L_base.stl
3D designs/Game Controller/L_base.ipt
3D designs/Game Controller/L_cover.ipt
3D designs/Game Controller/L_js_mount.ipt
3D designs/Game Controller/L_palm_pad.ipt
3D designs/Game Controller/R_base.ipt
3D designs/Game Controller/R_cover.ipt
3D designs/Game Controller/R_js_mount.ipt
3D designs/Game Controller/R_palm_pad.ipt
3D designs/Game Controller/centric_shaft_controller_smaller.iam
3D designs/Game Controller/drawings/OldVersions/Game Controller.0005.dwg
3D designs/Game Controller/drawings/OldVersions/Game Controller.0006.dwg
3D designs/Game Controller/js_nibble.ipt
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

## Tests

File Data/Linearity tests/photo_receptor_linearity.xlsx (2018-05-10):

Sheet: Sheet1
left side (soft springs, 2.7N/mm UL3-5) |  | 21.5 | 20.5 | 20 | 19.5 | 19 | 18.5 | 18 | 17.5 | right side (stiff springs, 27N/mm WB-5) | 21 | 20.8 | 20.5 | 20 | 19.5 | 19 | 18.5
21.5 | 795 | 792.8756934 | 791.9346739 | 772.3300485 | 740.7432184 | 700.6156463 | 647.6989644 | 589.8230742 | 492.5566509 |  | 784.4027315 | 776.7242949 | 766.0493069 | 747.9446897 | 709.1208725 | 666.5243386 | 613.5682192
21 | 792 | 1.646137992 | 1.244340149 | 1.289108407 | 1.290791195 | 1.222825335 | 1.272942022 | 34.85513659 | 1.228166518 |  | 2.134125482 | 2.196822665 | 1.767592293 | 1.775862879 | 2.096135096 | 1.867911626 | 1.354728467
20.5 | 777
20 | 755 | 791.98 | 792.99 | 774.98 | 742.96 | 702 | 649.97 | 5.94 | 492.99 |  | 786.01 | 778 | 766.97 | 749.96 | 708.99 | 660.99 | 616.94
19.5 | 728 | 789.99 | 792 | 772.97 | 739.02 | 701.99 | 647.01 | 593.97 | 492 |  | 786.97 | 777.97 | 764.03 | 746.03 | 707.99 | 660 | 611.03
19 | 680 | 789 | 792 | 770.02 | 741 | 701.02 | 648 | 591.02 | 492.01 |  | 783.98 | 775 | 766.98 | 748.97 | 707 | 660.04 | 614
18.5 | 576 | 789.01 | 792 | 772.01 | 740.98 | 702.98 | 648 | 593 | 493 |  | 782.03 | 775.03 | 765 | 746.03 | 707 | 663.98 | 613.99
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

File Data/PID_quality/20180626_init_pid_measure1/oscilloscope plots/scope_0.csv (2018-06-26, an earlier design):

x-axis | 1 | 2
second | Volt | Volt
-249.8000E-03 | +641.6156E-03 | +2.5728643E+00
-249.5500E-03 | +670.5100E-03 | +2.5326633E+00
-249.3000E-03 | +661.7161E-03 | +2.5728643E+00
-249.0500E-03 | +700.6608E-03 | +2.7286432E+00
-248.8000E-03 | +681.8166E-03 | +2.5728643E+00
-248.5500E-03 | +701.9171E-03 | +2.6884422E+00
-248.3000E-03 | +701.9171E-03 | +2.7286432E+00
-248.0500E-03 | +722.0176E-03 | +2.6532663E+00
-247.8000E-03 | +722.0176E-03 | +2.7286432E+00
-247.5500E-03 | +750.9121E-03 | +2.6934673E+00
-247.3000E-03 | +762.2186E-03 | +2.6532663E+00
-247.0500E-03 | +772.2688E-03 | +2.6884422E+00
-246.8000E-03 | +782.3191E-03 | +2.8090452E+00
-246.5500E-03 | +782.3191E-03 | +2.8140703E+00
-246.3000E-03 | +802.4196E-03 | +2.8140703E+00
-246.0500E-03 | +812.4698E-03 | +2.8140703E+00
-245.8000E-03 | +822.5201E-03 | +2.8140703E+00
-245.5500E-03 | +822.5201E-03 | +2.8944723E+00
-245.3000E-03 | +842.6206E-03 | +2.8140703E+00
-245.0500E-03 | +852.6708E-03 | +2.8944723E+00
-244.8000E-03 | +862.7211E-03 | +2.8944723E+00
-244.5500E-03 | +871.5151E-03 | +2.8944723E+00
-244.3000E-03 | +882.8216E-03 | +2.8140703E+00
-244.0500E-03 | +892.8719E-03 | +2.8492462E+00
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

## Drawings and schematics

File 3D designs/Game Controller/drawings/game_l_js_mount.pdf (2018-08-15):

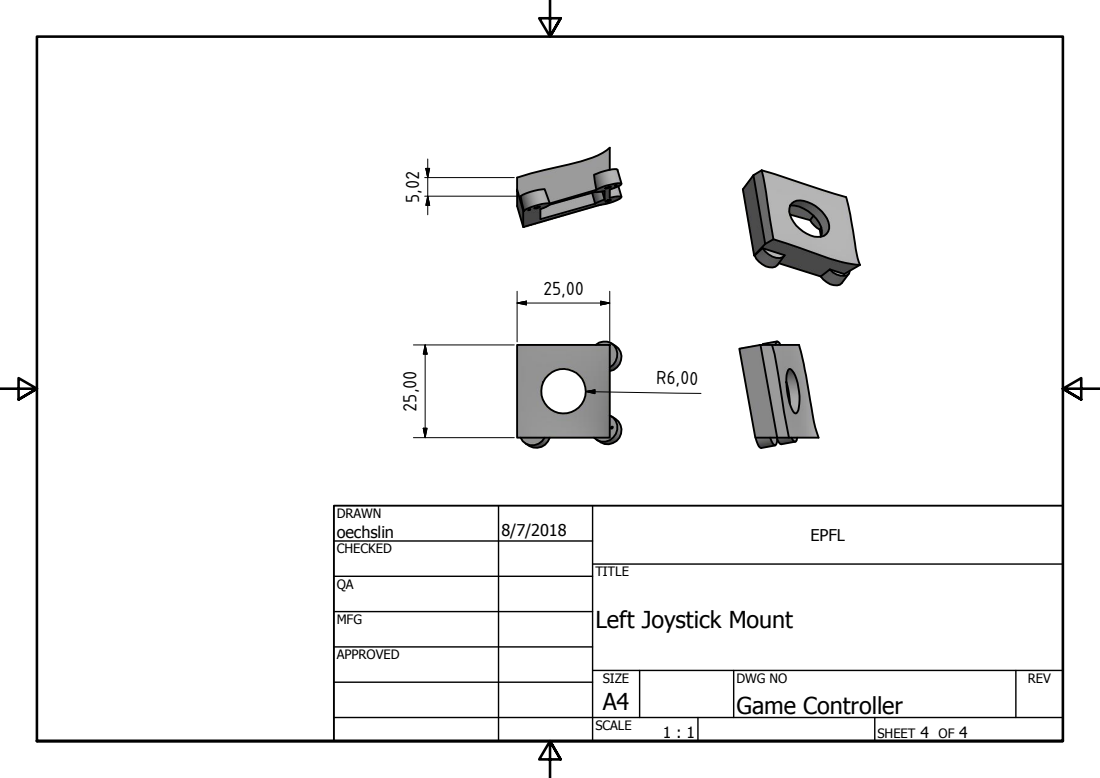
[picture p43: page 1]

DRAWN oechslin | 8/7/2018 | EPFL

CHECKED

TITLE
Left Joystick Mount

MFG

APPROVED

SIZE A4 | DWG NO Game Controller | REV

SCALE 1 : 1 | | SHEET 4 OF 4

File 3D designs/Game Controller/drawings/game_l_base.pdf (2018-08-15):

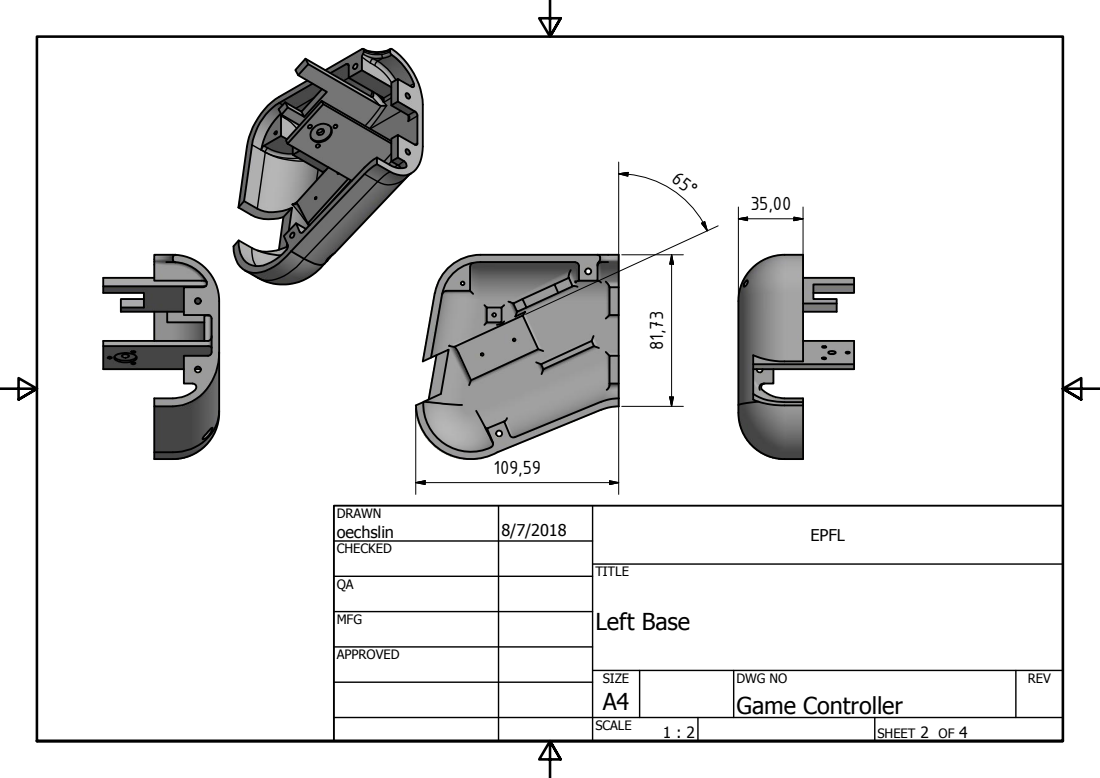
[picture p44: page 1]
Left Base

DRAWN oechslin | 8/7/2018 | EPFL

CHECKED

MFG

APPROVED

SIZE A4 | DWG NO Game Controller | REV

SCALE 1 : 2 | | SHEET 2 OF 4

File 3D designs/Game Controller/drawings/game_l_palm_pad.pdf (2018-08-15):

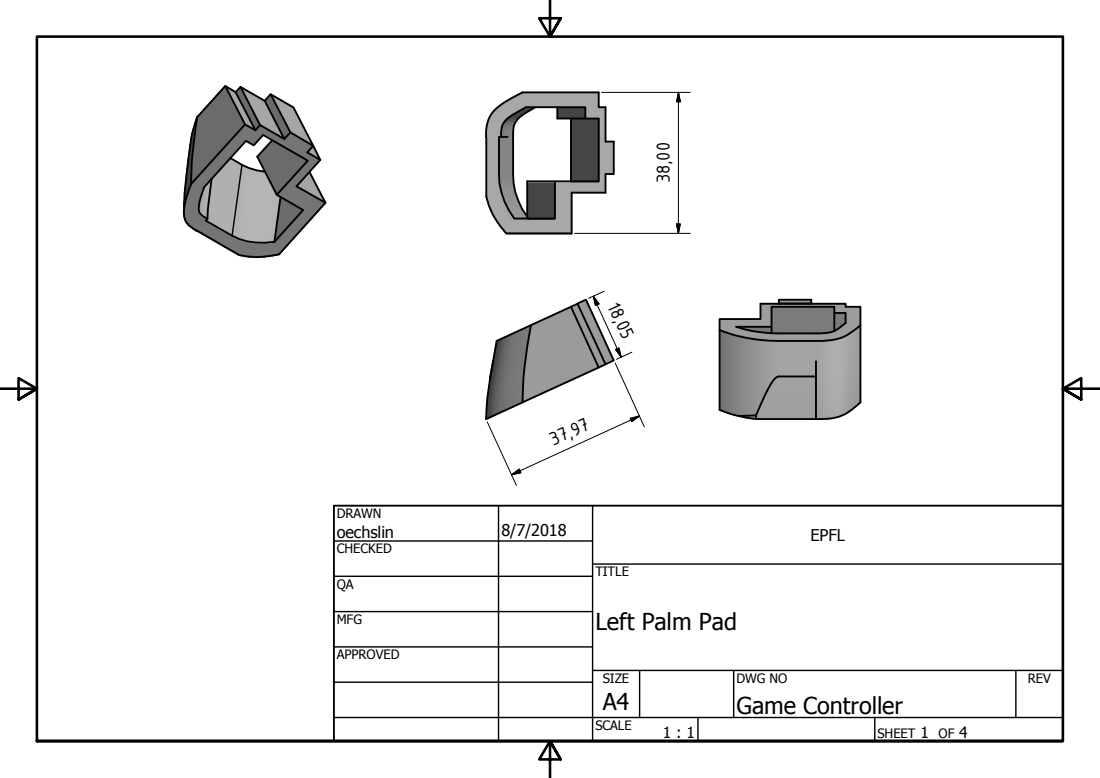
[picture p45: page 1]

DRAWN oechslin | 8/7/2018 | EPFL

CHECKED

Left Palm Pad

MFG

APPROVED

SIZE A4 | DWG NO Game Controller | REV

SCALE 1 : 1 | | SHEET 1 OF 4

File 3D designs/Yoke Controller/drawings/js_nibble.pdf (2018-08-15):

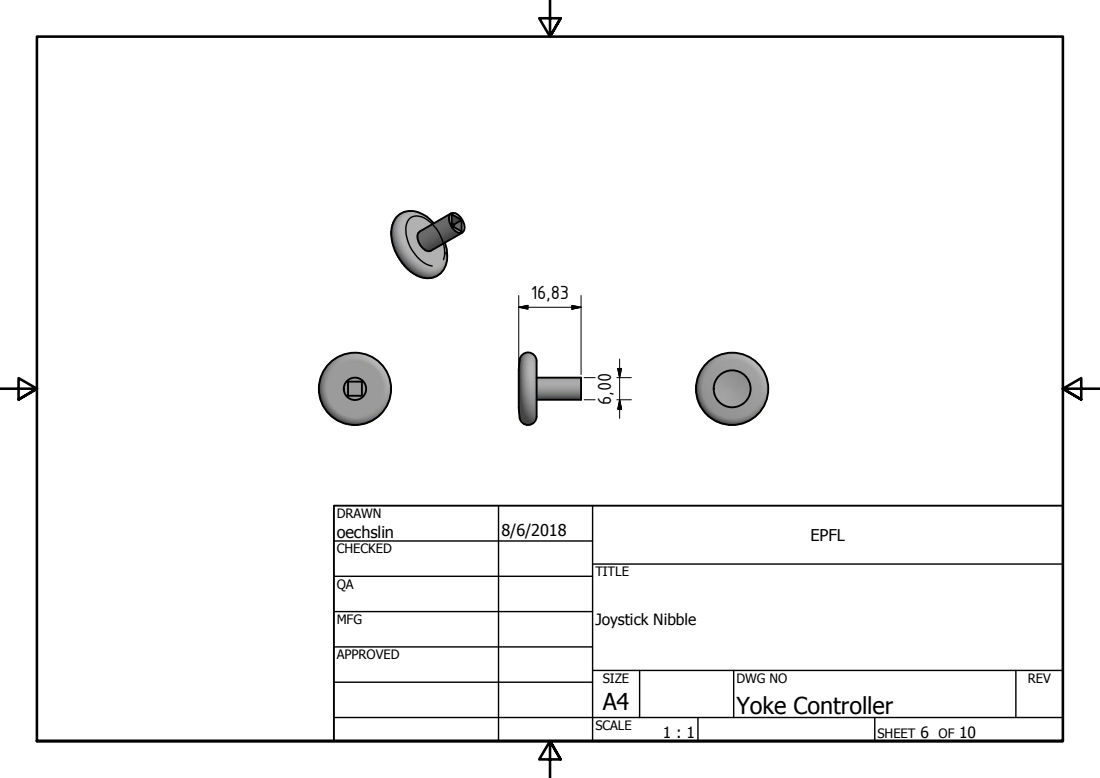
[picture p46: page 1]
Joystick Nibble

DRAWN oechslin | 8/6/2018 | EPFL

CHECKED

MFG

APPROVED

SIZE A4 | DWG NO Yoke Controller | REV

SCALE 1 : 1 | | SHEET 6 OF 10

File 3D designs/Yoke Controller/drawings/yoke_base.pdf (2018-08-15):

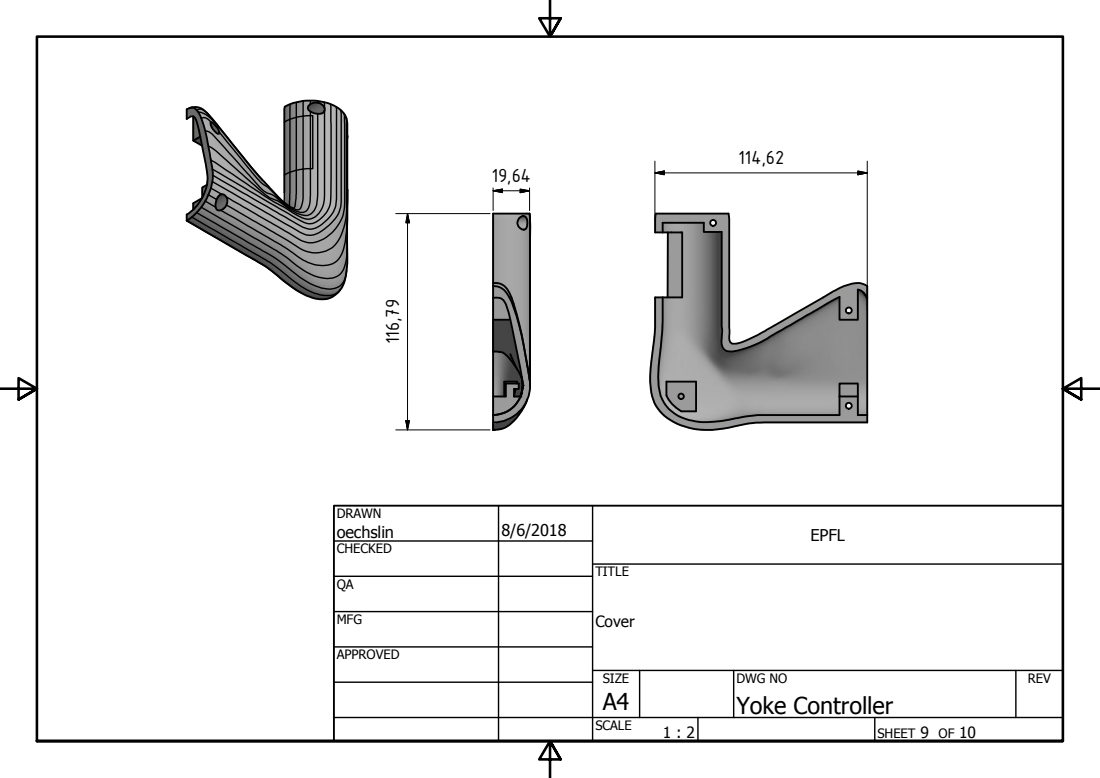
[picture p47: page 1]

DRAWN oechslin | 8/6/2018 | EPFL

CHECKED

MFG

APPROVED

SIZE A4 | DWG NO Yoke Controller | REV

SCALE 1 : 2 | | SHEET 9 OF 10

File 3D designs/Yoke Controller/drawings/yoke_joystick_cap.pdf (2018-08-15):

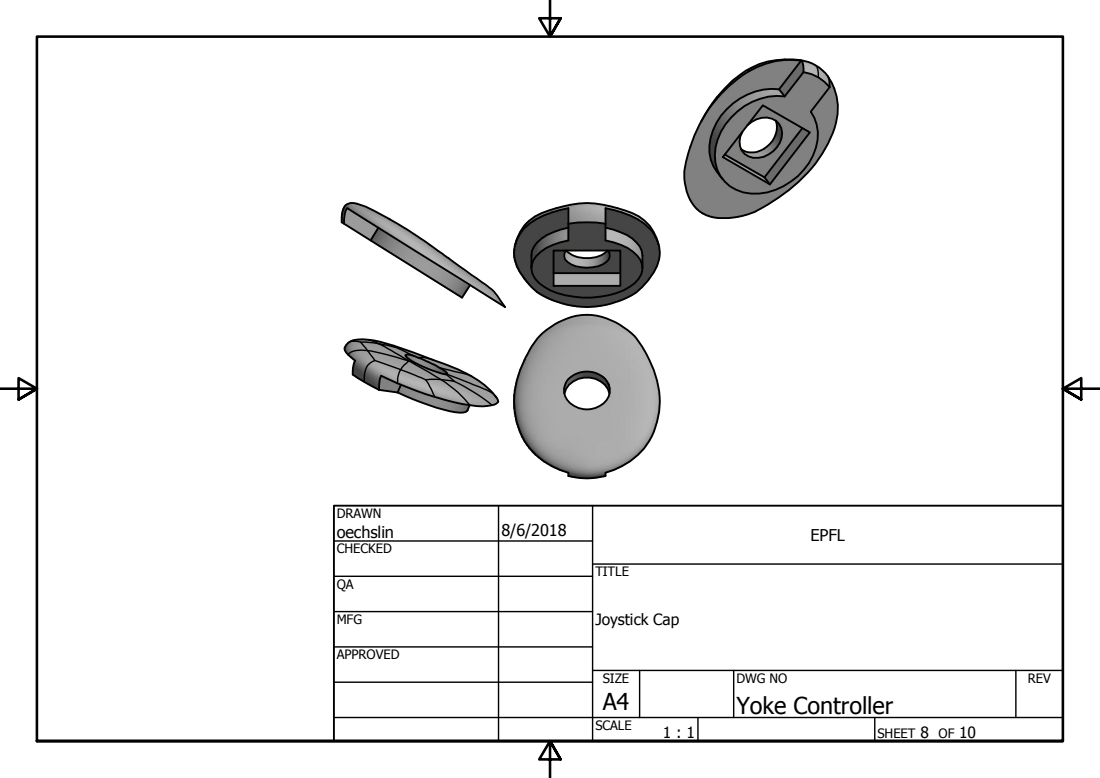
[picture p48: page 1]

D RA W N o e c h sli n | 8 / 6 / 2 0 1 8 | E P F L

S I Z E A 4 | D W G N O Y o k e C o n t r olle r | R E V

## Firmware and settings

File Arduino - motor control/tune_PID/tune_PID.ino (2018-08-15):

/*
  Roman Oechslin
  Robot controller with haptic feedback
  2018/04/06  Tokyo`
*/
#define FASTADC 1

// defines for setting and clearing register bits
#ifndef cbi
#define cbi(sfr, bit) (_SFR_BYTE(sfr) &= ~_BV(bit))
#endif
#ifndef sbi
#define sbi(sfr, bit) (_SFR_BYTE(sfr) |= _BV(bit))
#endif


#define joystick_left_pin A0
#define photo_left_pin A2
#define joystick_right_pin A1
#define photo_right_pin A3
#define sine_signal_pin A5
int motorPinLowGain = 3;    // Motor connected to digital pin 3 (PWM)
int motorPinHighGain = 11;    // Motor connected to digital pin 11 (PWM)
int testPin = 13; // Used for testing the speed of Arduino
int controlPin = 6; // Used for checking the distance

int sine_signal = 0;
int photo_value_left_raw = 0;
int photo_value_right_raw = 0;

int dist_ref = 0;
int OUTPUT_PER_VOLT = 255 / 5; // the arduino can output 5V max
int MOTOR_MAX_VOLTAGE = 20; // change this according to motor
int LEFT_HAND_AMPLIFIER_GAIN = 10;
int RIGHT_HAND_AMPLIFIER_GAIN = 10;
const int OUTPUT_RANGE_L = 2 * MOTOR_MAX_VOLTAGE * OUTPUT_PER_VOLT / LEFT_HAND_AMPLIFIER_GAIN;
const int OUTPUT_RANGE_R = 2 * MOTOR_MAX_VOLTAGE * OUTPUT_PER_VOLT / RIGHT_HAND_AMPLIFIER_GAIN;

float error_left = 0;
//float last_error_left = 0;
float sum_error_left = 0;
float error_right = 0;
//float last_error_right = 0;
float sum_error_right = 0;
float dT = 0.001;
float filter_coeff = 0.01;
float error_left_last = 0;
float error_right_last = 0;
float numerator_l_last_f = 0;
float numerator_r_last_f = 0;

const int PHOTO_MIN_LEFT = 640;
const int PHOTO_MAX_LEFT = 840;
const int PHOTO_MIN_RIGHT = 700;
const int PHOTO_MAX_RIGHT = 880;
const int MAX_DISPLACEMENT_UM = 1800; // [um], has been measured

char buf[16];
char all[512];
char *p = all;
char *init_p = all;
char semicolon[5] = ";";
char end_char[5] = "\n";

unsigned long TIME_BEGIN = 0;
unsigned long TIME_NOW = 0;
unsigned long TIME_CYCLE = 1000; // this is the time_step in [us] that determines the running frequency

int test_valpid = 0;
void setup() {
  Serial.begin(250000);
  pinMode(motorPinLowGain, OUTPUT);
  pinMode(motorPinHighGain, OUTPUT);

  pinMode(sine_signal_pin, INPUT);
  pinMode(joystick_left_pin, INPUT);
  pinMode(photo_left_pin, INPUT);
  pinMode(joystick_right_pin, INPUT);
  pinMode(photo_right_pin, INPUT);
  pinMode(testPin, OUTPUT);
  pinMode(controlPin, OUTPUT);

  TCCR2B = TCCR2B & B11111000 | B00000001; // for PWM frequency of 31372.55 Hz

  #if FASTADC
    // set prescale to 16
    sbi(ADCSRA, ADPS2) ;
    cbi(ADCSRA, ADPS1) ;
    cbi(ADCSRA, ADPS0) ;
  #endif
}

void loop() {
  digitalWrite(testPin, HIGH); // this is only used to measure the operating frequency
  TIME_BEGIN = micros();

  sine_signal = analogRead(sine_signal_pin);
  photo_value_left_raw = analogRead(photo_left_pin);
  photo_value_right_raw = analogRead(photo_right_pin);

  int pwmValueLeftSym = 128;
  int pwmValueRightSym = 128;

  // k_p = 0.243; k_i = 0.63; k_d =0.00126; works well
  //1.6; // k_p = 0.8; and k_i = 0.01; k_d = 0.008; works not so well
  float k_p = 0.243;
  float k_i = 0.63;
  float k_d = 0.00126;

  // ignore Serial and read sine wave signal as reference
  dist_ref = sine2dist(sine_signal);
  error_left = dist_ref - sensor2dist(photo_value_left_raw, PHOTO_MIN_LEFT, PHOTO_MAX_LEFT);
  error_right = dist_ref - sensor2dist(photo_value_right_raw, PHOTO_MIN_RIGHT, PHOTO_MAX_RIGHT);
  
  sum_error_left = error_left + sum_error_left;
  sum_error_right = error_right + sum_error_right;
  float numerator_l = error_left - error_left_last;
  float numerator_r = error_right - error_right_last;
  float numerator_l_f = numerator_l*filter_coeff + numerator_l_last_f * (1-filter_coeff);
  float numerator_r_f = numerator_r*filter_coeff + numerator_r_last_f * (1-filter_coeff);

  numerator_l_last_f = numerator_l_f;
  numerator_r_last_f = numerator_r_f;
  error_left_last = error_left;
  error_right_last = error_right;
  
  int des_mot_volt_left = k_p * error_left + k_i * sum_error_left*dT + k_d * numerator_l_f/dT;
  int des_mot_volt_right =  k_p * error_right + k_i * sum_error_right*dT + k_d * numerator_r_f/dT;

  // symmetric feedback left and right, (allowing for negative motor values)
  pwmValueLeftSym = pid2pwm_sym(des_mot_volt_left, OUTPUT_RANGE_L);
  pwmValueRightSym = pid2pwm_sym(des_mot_volt_right, OUTPUT_RANGE_R);

  analogWrite(motorPinLowGain, pwmValueLeftSym); //pwmValueLeftSym
  analogWrite(motorPinHighGain, pwmValueRightSym); //pwmValueRightSym
  
  //fastest way of writing data to serial
  all[0] = '\0';
  p = mystrcat(init_p, itoa(dist_ref, buf, 16));
  p = mystrcat(p, semicolon);
  p = mystrcat(p, itoa(photo_value_left_raw, buf, 16));
  p = mystrcat(p, semicolon);
  p = mystrcat(p, itoa(photo_value_right_raw, buf, 16));
  p = mystrcat(p, semicolon);
  p = mystrcat(p, itoa(TIME_BEGIN, buf, 16));
  p = mystrcat(p, semicolon);
  p = mystrcat(p, end_char);
  Serial.print(all); //TODO this is necessary for logging
  // message format: dist ref | left val | right val | time stamp

  /*
  Serial.print("ref = ");
  Serial.println(dist_ref);
  Serial.print("photo_value_right_raw = ");
  Serial.println(photo_value_right_raw);
  Serial.print("error = ");
  Serial.println(error_right);
  Serial.print("des_mot_volt_right = ");
  Serial.println(des_mot_volt_right);
  Serial.print("pwmValueRightSym = ");
  Serial.println(pwmValueRightSym);

  Serial.print("measured dist = ");
  Serial.println(sensor2dist(photo_value_right_raw, PHOTO_MIN_RIGHT, PHOTO_MAX_RIGHT));
  Serial.print("error right = ");
  Serial.println( error_right);
  Serial.print("proportional term = ");
  Serial.println(k_p * error_right);
  Serial.print("integral term = ");
  Serial.println( k_i * sum_error_right);
  Serial.print("derivative term = ");
  Serial.println(k_d * numerator_r_f/dT);
  Serial.print("numerator_r = ");
  Serial.println( numerator_r);*/
  
  while ((micros() - TIME_BEGIN) < TIME_CYCLE) {  } // do nothing until we reach the time step of TIME_CYCLE
  digitalWrite(testPin, LOW); //instructions in between take roughly 640 microseconds
  analogWrite(controlPin, 255-map(photo_value_right_raw,PHOTO_MIN_RIGHT, PHOTO_MAX_RIGHT, 0, 255)); 
  //analogWrite(controlPin, 255-map(photo_value_left_raw,PHOTO_MIN_LEFT, PHOTO_MAX_LEFT, 0, 255));  
}


char* mystrcat( char* dest, char* src )
{
  // taken from https://stackoverflow.com/questions/21880730/c-what-is-the-best-and-fastest-way-to-concatenate-strings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
  while (*dest) dest++;
  while (*dest++ = *src++);
  return --dest;
}

int sine2dist(int sine){
  return (((sine / 4) * (MAX_DISPLACEMENT_UM / 15) / 16) * 15) / 16; 
  // sine / 1024 * MAX_DISPLACEMENT_UM had to be rewritten due to overflow
}

int sensor2dist(int sensor_value, int min_val, int max_val) {
  // maps the measured value to the distance (assumed linearity) in micrometers
  return MAX_DISPLACEMENT_UM - (sensor_value - min_val) * (MAX_DISPLACEMENT_UM /15) / (max_val - min_val) * 15;
}


int limit_value(int value, int lower, int upper) {
  if (value < lower) {
    value = lower;
  } else if (value > upper) {
    value = upper;
  }
  return value;
}

int pid2pwm_sym(int des_voltage, int range) {
  // converts motor voltage to pwm output where 128-range/2 is full power in one direction and 128+range/2 is 
  // full power in the other
  return limit_value(des_voltage, -range/2, range/2) + 128;
}

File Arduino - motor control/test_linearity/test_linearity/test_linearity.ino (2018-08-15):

/*
  Roman Oechslin
  Robot controller with haptic feedback
  2018/04/06  Tokyo
*/

#define joystick_left_pin A0
#define photo_left_pin A2
#define joystick_right_pin A1
#define photo_right_pin A3
#define sine_signal_pin A5
int motorPinLowGain = 3;    // Motor connected to digital pin 3 (PWM)
int motorPinHighGain = 11;    // Motor connected to digital pin 11 (PWM)
int testPin = 13; // Used for testing the speed of Arduino

int dist_ref = 0;
float FILTER_CST = 0.5;
int OUTPUT_PER_VOLT = 255/5; // the arduino can output 5V max
int MOTOR_MAX_VOLTAGE = 20; // change this according to motor
int LEFT_HAND_AMPLIFIER_GAIN = 10;
int RIGHT_HAND_AMPLIFIER_GAIN = 10;
bool USE_JOYSTICK_DIRECT_LINK = false;

int error_left = 0; 
int last_error_left = 0;
int sum_error_left = 0;
int error_right = 0; 
int last_error_right = 0;
int sum_error_right = 0;
const int PHOTO_MIN_LEFT = 514;
const int PHOTO_MAX_LEFT = 787;
const int PHOTO_MIN_RIGHT = 678;
const int PHOTO_MAX_RIGHT = 773;

char buf[16];
char all[512];
char *p = all;
char *init_p = all;
char semicolon[5] = ";";
char end_char[5] = "\n";

unsigned long TIME_BEGIN = 0;
unsigned long TIME_NOW = 0;
unsigned long TIME_CYCLE = 1000; // this is the time_step in [microseconds] that determines the running frequency


void setup() {
  Serial.begin(115200);
  pinMode(motorPinLowGain, OUTPUT);
  pinMode(motorPinHighGain, OUTPUT);
  
  pinMode(sine_signal_pin, INPUT);
  pinMode(joystick_left_pin, INPUT);
  pinMode(photo_left_pin, INPUT);
  pinMode(joystick_right_pin, INPUT);
  pinMode(photo_right_pin, INPUT);
  pinMode(testPin, OUTPUT);

  TCCR2B = TCCR2B & B11111000 | B00000001; // for PWM frequency of 31372.55 Hz
}

void loop() {
  digitalWrite(testPin, HIGH); // this is only used to measure the operating frequency
  TIME_BEGIN = micros();
  
  int sine_signal = analogRead(sine_signal_pin);
  
  int joy_val_left = analogRead(joystick_left_pin);
  joy_val_left = joy_val_left>>2; // the joystick value is [0..1023] and I want to convert it to 8bit
  int joy_val_right = analogRead(joystick_right_pin);
  joy_val_right = joy_val_right>>2; // the joystick value is [0..1023] and I want to convert it to 8bit

  
  int photo_value_left_raw = analogRead(photo_left_pin);
  int photo_value_right_raw = analogRead(photo_right_pin);

  int pwmValueLeft = 0;
  int pwmValueRight = 0;
  int pwmValueLeftSym = 128;
  int pwmValueRightSym = 128;
  
  if (USE_JOYSTICK_DIRECT_LINK) {
    pwmValueLeft = output2pwm_sym((joy_val_left-127)>0?joy_val_left:0, LEFT_HAND_AMPLIFIER_GAIN);
    pwmValueRight = output2pwm_sym((joy_val_right-127)>0?joy_val_right:0, RIGHT_HAND_AMPLIFIER_GAIN);
  } else {
    float k_p = 1.0; // k_p = 1; and k_i = 0.01; works as well
    float k_i = 0.0;
    float k_d = 0.0;
    int photo_value_left = limit_value(photo_value_left_raw, PHOTO_MIN_LEFT, PHOTO_MAX_LEFT);
    int photo_value_right = limit_value(photo_value_right_raw, PHOTO_MIN_RIGHT, PHOTO_MAX_RIGHT);
    // just to be sure that it is not out of expected boundaries

    // ignore Serial and read sine wave signal as reference
    dist_ref = sine_signal >> 2;
    error_left = dist_ref - map_to_255(photo_value_left, PHOTO_MIN_LEFT, PHOTO_MAX_LEFT);
    error_right = dist_ref - map_to_255(photo_value_right, PHOTO_MIN_RIGHT, PHOTO_MAX_RIGHT);
        
    int motor_output_left = k_p * error_left + k_i * sum_error_left + k_d * (error_left - last_error_left);
    int motor_output_right =  k_p * error_right + k_i * sum_error_right + k_d * (error_right - last_error_right);//FIXME need two different control parameters?
    sum_error_left = error_left + sum_error_left;
    last_error_left = error_left;
    sum_error_right = error_right + sum_error_right;
    last_error_right = error_right;
    // symmetric feedbackLeft, (allowing for negative motor values)
    pwmValueLeftSym = output2pwm_sym(motor_output_left, LEFT_HAND_AMPLIFIER_GAIN); //motor_output_left
    // symmetric feedbackRight, (allowing for negative motor values)
    pwmValueRightSym = output2pwm_sym(motor_output_right, RIGHT_HAND_AMPLIFIER_GAIN);

  }
  analogWrite(motorPinLowGain, 230);//pwmValueLeftSym
  analogWrite(motorPinHighGain, pwmValueRightSym); //pwmValueRightSym
  Serial.println(photo_value_left_raw); // this is necessary for logging
  
  while ((micros() - TIME_BEGIN) < TIME_CYCLE) {  } // do nothing until we reach the time step of TIME_CYCLE
  digitalWrite(testPin, LOW); //instructions in between take roughly 640 microseconds
}


char* mystrcat( char* dest, char* src )
{
  // taken from https://stackoverflow.com/questions/21880730/c-what-is-the-best-and-fastest-way-to-concatenate-strings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
  while (*dest) dest++;
  while (*dest++ = *src++);
  return --dest;
}

int map_to_255(int receptor_value, int min_val, int max_val) {
  // this function maps the measured value to the feedback range [0..255]
  int converted = (receptor_value - min_val) * 51 / (max_val - min_val) * 5;
  converted = 255 - converted;
  return converted;
}

int limit_value(int value, int lower, int upper) {
  if (value < lower) {
    value = lower;
  } else if (value > upper) {
    value = upper;
  }
  return value;
}

int output2pwm_sym(int output, float gain) {
  // This function converts the reference symmetrically into a PWM where 0 is full power in one direction and 255 is full power in the other
  // Due to the non exactness of the sensor MIN and MAX values, this still results in some asymmetries however
  // conversion of feedback to pwm[0..255]:
  
  // limit to MAX_VOLTAGE
  int limit_val = 2 * MOTOR_MAX_VOLTAGE * OUTPUT_PER_VOLT / gain;
  float pwm = (float) output / 16 * limit_val / (32) + limit_val / 2;
  return limit_value((int) pwm, 0, limit_val);
}

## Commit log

2018-05-10 set arduino frequency to 1 kHz
2018-05-10 Extend arduino file for frequency response test
2018-05-10 change arduino file to test linearity
    [photo_receptor_linearity.xlsx]
2018-05-10 change back to working motor control
2018-05-11 make test for linearity
    [photo_receptor_linearity.xlsx]
2018-05-28 convert raw hex data to int csv files
    [f1.25_csv.csv, f1.6_csv.csv, f100_csv.csv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]
2018-05-29 measure data with max voltage applied
    [max_volt_applied.xlsx]
2018-05-29 Plot max applied voltage
    [max_volt_applied.xlsx]
2018-05-29 plot bode diagrams in data analysis
    [f2_csv.csv]
2018-05-29 add a second dataset for frequency response analysis
    [f1.25_csv.csv, f1.6_csv.csv, f100_csv.csv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]
2018-05-31 gather more data, create more figures, change speed in arduino control
2018-06-01 invert max volt applied
    [max_volt_applied.xlsx]
2018-06-20 general revision of arduino code
    [check_amplitude_following_dec.csv, check_amplitude_following_hex.csv, data_applied_reference_no_voltage follower2Hz.csv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]
2018-06-21 adapt data_analysis code a lot (unfortunately took non-up-to-date version from this branch), however should be up to date now, creating figures of newest experiment with voltage follower
    [check_amplitude_following_dec.csv, check_amplitude_following_hex.csv, f1.25_csv.csv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]
2018-06-22 do analysis of the data from 21st of June (voltage follower)
2018-06-26 update motor control file, created pid_tuning related files and data
    [scope_0.csv, scope_1.csv, scope_10.csv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]
2018-06-27 add pid data and change ardu file
    [f1.25_csv.csv, f1.6_csv.csv, f100_csv.csv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]
2018-06-29 data update, pid update
    [f1.25_csv.csv, f1.6_csv.csv, f100_csv.csv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]
2018-07-02 pid tuning
2018-07-03 identify pid gains, retake bode measurements
    [f1.25_csv.csv, f1.6_csv.csv, f100_csv.csv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]
2018-07-03 prepare for testing PID on robot
2018-07-03 typos in arduino file
2018-07-03 test feedback on real controller coupled with robot
2018-07-04 redo bode with PID since motor had some gear issues
    [f1.25_csv.csv, f1.6_csv.csv, f100_csv.csv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]
2018-07-04 create figures for 1 and 10 percent filter
    [f1.25_csv.csv, f1.6_csv.csv, f100_csv.csv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]
2018-07-04 plot tracking performance
    [tracking15_csv.csv, tracking16_csv.csv, tracking17_csv.csv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]
2018-07-13 finish testing of PS controller
    [scope_0.csv, scope_1.csv, scope_2.csv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]
2018-07-16 added 3D files for Pilot controller
    [Base.ipt, Cover.ipt, Motor_plate.ipt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]
2018-07-17 measure sensor thresholds
2018-07-18 write report, plot command response
    [scope_3.csv]
2018-07-18 clean 3d files of ps and pilot controller
    [L_base.ipt, L_base.stl, L_cover.ipt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]
2018-07-19 make bode analysis for pilot controller
    [f1.25_csv.csv, f1.6_csv.csv, f100_csv.csv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]
2018-07-20 plots for unity latency/feedback tracking
    [scope_0.csv, scope_1.csv, scope_10.csv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]
2018-07-20 report writing, figure updating
    [scope_13.csv, scope_14.csv, scope_3.csv]
2018-07-26 analyse pilot real robot testing
    [scope_0.csv, scope_1.csv, scope_13.csv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]
2018-07-27 new bode plotting with pilot controller
    [f1.25_csv.csv, f1.6_csv.csv, f100_csv.csv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]
2018-07-31 hysteresis test
    [pilot_hysteresis_P15_2_dec.csv, pilot_hysteresis_P15_dec.csv, pilot_hysteresis_P15_dec_trial.csv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]
2018-07-31 switch axes
2018-07-31 graphs pilot unity
    [scope_0.csv, scope_1.csv, scope_2.csv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]
2018-07-31 latency scopes
    [scope_0.csv, scope_1.csv, scope_2.csv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]
2018-07-31 redid hysteresis plot
    [pilot_hysteresis_2_dec.csv, pilot_hysteresis_3_dec.csv, pilot_hysteresis_dec.csv]
2018-08-01 create tracking performance plots
    [scope_0.csv, scope_1.csv, scope_2.csv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]
2018-08-01 renamed file
    [L_base.ipt, L_base.stl, L_cover.ipt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]
2018-08-07 clean up 3d-files, add drawings, clean up code
    [Base.ipt, Cover.ipt, Drawing1.0008.dwg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]
2018-08-14 data analysis for unity scope plots
    [scope_0.csv, scope_1.csv, scope_2.csv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]
2018-08-14 add osc data plots for new unity testing figures
    [a.csv, a1.csv, a2.csv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]
2018-08-15 major code revision and merging procedure
    [a.csv, a1.csv, a2.csv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]
